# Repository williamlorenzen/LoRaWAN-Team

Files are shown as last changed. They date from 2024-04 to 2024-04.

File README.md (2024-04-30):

<!-- PROJECT LOGO -->
<br />
<p align="center">
  <a href="https://github.com/williamlorenzen/LoRaWAN-Team">
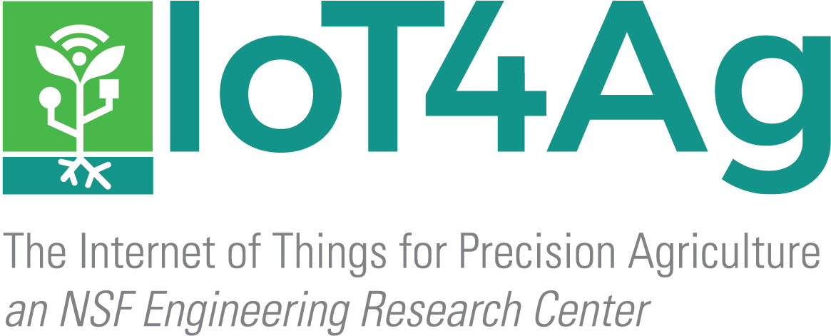
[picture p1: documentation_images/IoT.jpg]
    
  </a>

  <h2 align="center" style="font-size: 48px;">LoRaWAN Asset Tracker and Emergency Button</h2>

  <p align="center" style="font-size: 32px;">
    <strong>Spring 2024 LoRaWAN Team</strong>
    <br />
    William Lorenzen, Maria Barrera, Justin Nagovskiy
  </p>
</p>

<!-- TABLE OF CONTENTS -->
<details open="open">
  <summary>Table of Contents</summary>

## Table of Contents
- [Background](#background)
  - [LoRaWAN Overview](#lorawan-overview)
  - [Problem Overview](#problem-overview)
  - [LoRaWAN as a Solution](#lorawan-as-a-solution)
- [System Architecture](#system-architecture)
- [TheThingsNetwork](#thethingsnetwork)
  - [TTN Background](#ttn-background)
  - [TTN Applications](#ttn-applications)
  - [End Device Registration](#end-device-registration)
- [ThingSpeak](#thingspeak)
  - [ThingSpeak Account Creation](#thingspeak-account-creation)
  - [ThingSpeak Visualizations and Reacts](#thingspeak-visualizations-and-reacts)
  - [ThingSpeak Account Setup](#thingspeak-account-setup)
  - [Text Message Notification Setup](#text-message-notification-setup)
- [Gateway](#gateway)
  - [Option 1](#option-1)
  - [Option 2](#option-2)
- [Operation](#operation)
  - [End Node](#end-node)
  - [GPS Operation](#gps-operation)
  - [Bluetooth Uplink Communication](#bluetooth-uplink-communication)
  - [Downlink Communication](#downlink-communication)
  - [Farm Communication System and Future Work](#farm-communication-system-and-future-work)
  - [Python GUI](#python-gui)
- [Authors](#authors)
- [Acknowledgements](#acknowledgements)
</details>

<!-- Background -->
## Background

### LoRaWAN Overview

<p align="center">
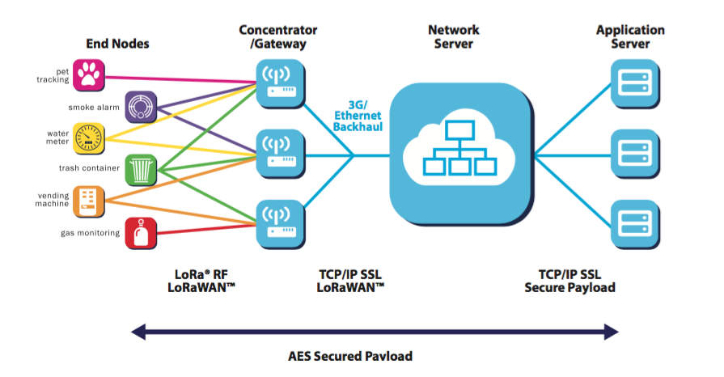
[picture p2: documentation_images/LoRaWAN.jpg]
	
</p>

LoRaWAN (Long Range Wide Area Network) is a networking protocol specially designed for low power, wide area applications. Introduced in the mid-2010s, LoRaWAN is known for its lower power consumption, cost-effectiveness, and longer range compared to traditional WiFi and cellular communications. However, it features lower bandwidth, which restricts its use for real-time, high data transfer applications. This makes LoRaWAN particularly well-suited for agricultural applications, where its long range and low power consumption are ideal for monitoring and reporting across extensive areas without requiring frequent battery recharges/replacements. To learn more about LoRaWAN, refer to [TheThingsNetwork's documentation](https://www.thethingsnetwork.org/docs/lorawan/).

### Problem Overview

The agricultural sector is recognized as one of the most hazardous industries in the United States, with a notable fatality rate of [23.5 per 100,000 workers](https://www.bls.gov/news.release/cfoi.nr0.htm). Two primary challenges complicate safety measures in this sector:

1. Asset Management: The extensive use of equipment and vast expanses of farmland make it difficult to monitor and manage assets effectively. Loss and misplacement of equipment are common issues, often highlighted during inventory checks.

2. Connectivity and Safety: Unreliable Wi-Fi and cellular connections in rural areas severely impact the implementation of safety measures. This connectivity gap poses a significant risk to worker safety, potentially leaving individuals isolated and unable to call for help during emergencies.

### LoRaWAN as a Solution

Given the limitations of conventional wireless communications like cellular and WiFi—namely their high cost and inadequate coverage in rural settings—LoRaWAN presents a viable alternative. Its low-cost, long-range capabilities allow for communication up to tens of kilometers in open conditions, addressing critical issues within the agricultural industry. 

To confront the safety and security concerns in the agricultural sector, our group developed a LoRaWAN-based end node that works as a personal emergency button as well as an asset tracker. Containing a GPS module, the end node collects its real time GPS coordinates and sends it in uplink messages to the server, along with other end node data, including the emergency status of the device, the battery voltage, and unique message codes that can be sent by field workers. Additionally, a Python application was created that will allow farm managers to view the real time GPS locations of the end nodes on a geolocation map, as well as the rest of the end node data. To ensure quick responses to emergencies, we have configured the server to send email and text notifications to relevant parties whenever the emergency button on the end node has been pressed. 

<!-- System Architecture -->
## System Architecture

<p align="center">
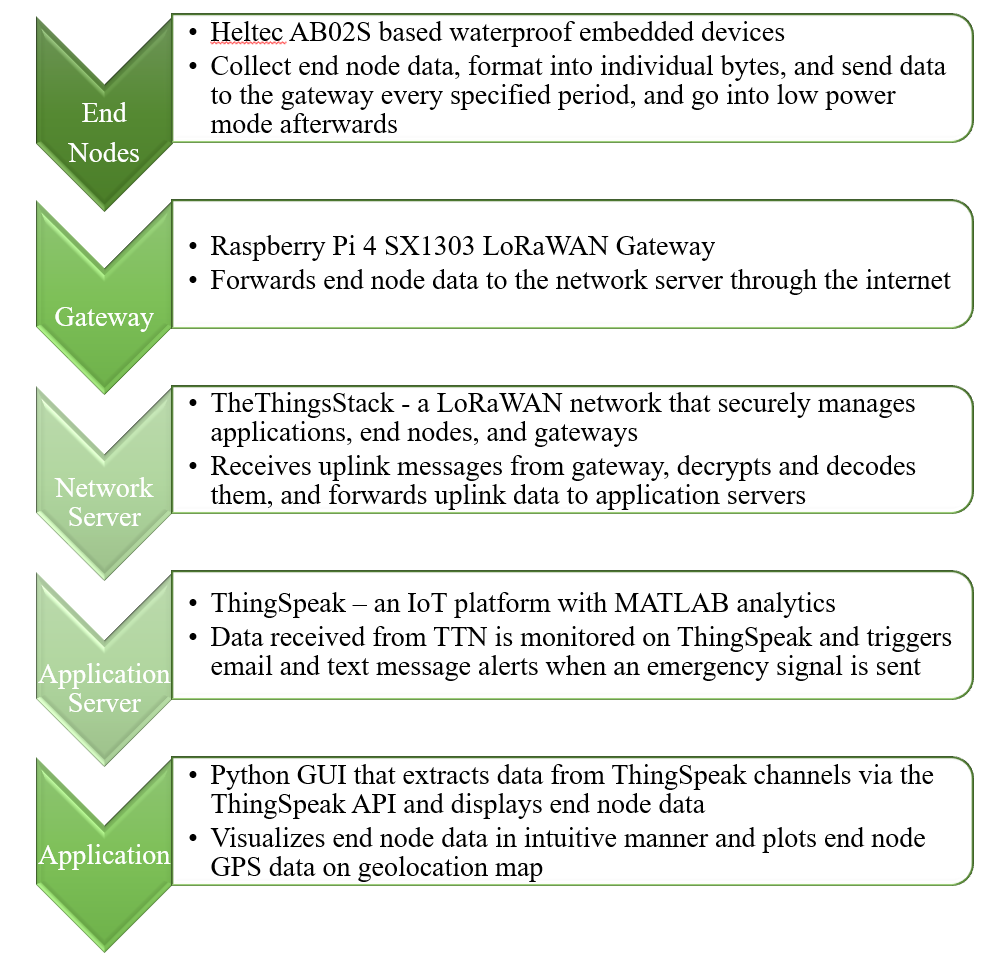
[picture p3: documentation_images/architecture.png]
	
</p>

Our system architecture is comprised of five primary components: the end nodes, the gateway, TheThingsNetwork, ThingSpeak, and a Python GUI. Please note that we refer to TheThingsStack, our network server, as TheThingsNetwork (TTN) in our documentation.

1. The end nodes are waterproof devices that are based around the [HTCC-AB02S](https://heltec.org/project/htcc-ab02s/), a development board that supports LoRaWAN communication and contains an Air530Z GPS and OLED display, making it optimal for our application. Please refer to the [hardware](hardware/) and [heltec_software](heltec_software/) folders, which each contain their own README files, for more information about the design of the end node.

2. The gateway is an SX1303 Raspberry Pi LoRaWAN gateway that was built and configured on TTN by the Fall 2023 LoRaWAN team. Additional information about the gateway and the instructions that the previous team used to set it up can be found [here](https://www.waveshare.com/wiki/SX1302_LoRaWAN_Gateway_HAT). If you want to learn how to set up a new gateway and configure it on TTN, refer to the [TTN documentation](https://www.thethingsindustries.com/docs/gateways/models/). The gateway is discussed in greater detail in the [Gateway section](#gateway).

3. TTN is our network server, where all of the uplink messages that are forwarded by the gateway are received, decoded, and forwarded to ThingSpeak. TTN is discussed in greater detail in the [TheThingsNetwork section](#thethingsnetwork).

4. ThingSpeak is our application server, where the data received from TTN is displayed and processed, allowing alerts to be triggered when an emergency signal is sent by an end node. Originally, we intended for ThingSpeak to act as the platform on which farm managers could view end node data and GPS locations, but due to limitations that are described in our report, we decided to develop a Python GUI to serve this purpose instead. The [ThingSpeak API](https://thingspeak.readthedocs.io/en/latest/api.html) allowed us to extract our end node data from ThingSpeak and use it in our GUI. ThingSpeak is discussed in greater detail in the [ThingSpeak section](#thingspeak) and [thingspeak_code](thingspeak_code/) folder.

5. The Python GUI extracts data from ThingSpeak, generating a fully interactive map displaying various end node locations and paths, as well as presenting end node data such as emergency status, battery charge, messages, and time since the last uplink message was received, all within a single interface. Please refer to the [gui_software](gui_software/) folder, which contains its own README file, for more information about the Python GUI.

For more detailed information about each of the system's components, please see our [final report on the project](resources/LoRaWAN_Spring_2024_Final_Report.pdf).

<!-- Operation -->
## TheThingsNetwork

### TTN Background 

TTN is the backbone of our system, with it receiving the uplink messages from our end nodes, decrypting and decoding the data, and forwarding the properly formatted data to ThingSpeak. TTN can also schedule downlink messages to particular end nodes, which we have implemented functionality for on our devices. 

On TTN, the gateway and end nodes must be configured appropriately in order to facilitate LoRaWAN communication. The LoRaWAN and Sentinel teams are using a shared TTN account for their implementations, on which the SX1303 gateway has already been configured. Future team members can reach out to [William](#authors) for the login information. As the gateway has already been configured on this shared account, configuration of the gateway on TTN will not be explained. TTN can be accessed [here](https://nam1.cloud.thethings.network/console/applications).

### TTN Applications

The important part of TTN for building upon our project or implementing other LoRaWAN based applications is the "Applications" tab. It is here that end devices are configured, which in our case is the HTCC-AB02S. We have designed our system so that each end node is configured in in its own unique application. This is because our TTN applications are configured to send decoded data to ThingSpeak, which then appears on ThingSpeak channels. The problem with these ThingSpeak channels is that there is a maximum of eight data fields per channel, meaning that a single ThingSpeak channel would not be able to handle the end node data of even two of our end nodes. Additionally, a single TTN application cannot be configured to send data from different end devices to separate ThingSpeak channels to circumvent the channel field limit. 

Therefore, we decided that our system would implement a dedicated TTN application for each of its end nodes, with each dedicated application sending end node data to a dedicated ThingSpeak channel. This way, each device was able to send eight fields of data to ThingSpeak, which was sufficient for our project and will allow future teams the bandwidth to send additional data from our end nodes, such as agricultural sensor data.

Establishing connection between TTN and ThingSpeak includes creating a webhook to a ThingSpeak channel from a TTN application. This process is explained in this [video](https://www.youtube.com/watch?v=b9Ga4nwnsTM).

### End Device Registration

The next step is to register an end device in an application. To do so: 

1. Click "Register end device" inside the relevant application.

2. Fill in the below information for the AB02S:

<p align="center">
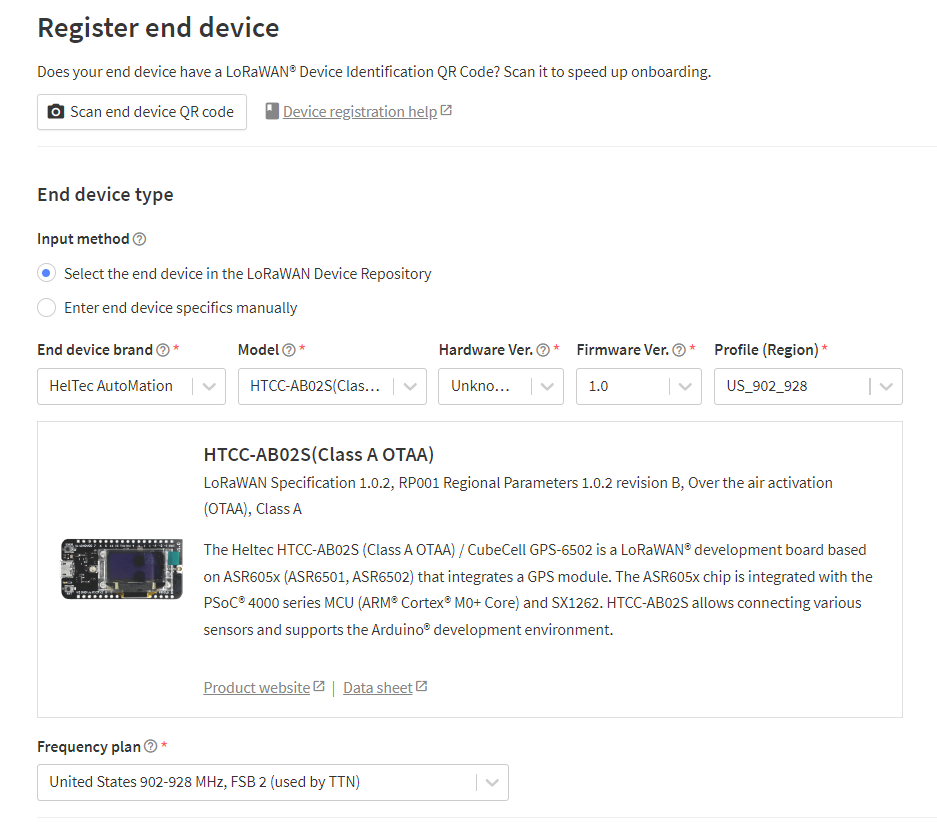
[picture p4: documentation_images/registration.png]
	
</p>

Depending on what brand or model that you use, the information may need to be different. But make sure you select your model with (Class A - OTAA), as is done in the image above. This is because end devices should be configured as Class A to reduce power draw, and OTAA communication should be used because it is more secure than ABP. More on [LoRaWAN classes](https://www.thethingsnetwork.org/docs/lorawan/classes/) and [communication types](https://www.thethingsnetwork.org/forum/t/what-is-the-difference-between-otaa-and-abp-devices/2723).

3. Input all 0's for the JoinEUI

4. Have TTN Generate the DevEUI and AppKey for you.

5. Go to your end node's script and update the DevEUI and AppKey to reflect the TTN generated information. For our project, this means going to the [GPS_LoRa script](heltec_software/GPS_LoRa/GPS_LoRa.ino) and updating the devEUI and appKEY arrays.

6. Click "Register end device." Your end device is now configured on TTN.

7. Click on the registered device and select "Payload Formatters."

8. For "Formatter type," select "Custom Javascript formatter."

9. Input your custom payload formatter, which decodes the payload that has been received from the end device. This should be tailored to the way in which you prepare your payload on your end node device. For our project, our TTN payload formatter was created according to how we filled the "appData" buffer in our GPS_LoRa.ino script. See the [heltec_software README](heltec_software/README.md) and [GPS_LoRA.ino script](heltec_software/GPS_LoRa/GPS_LoRa.ino) for more information. Our TTN payload formatter is below:

```
function Decoder(bytes) {
  // Decode an uplink message from a buffer
  var decoded = {};

  // Decode longitude
  var lng_frac_part = (bytes[0] | (bytes[1] << 8) | bytes[2] << 16);
  var lng_int_part = (bytes[3]);
  if (bytes[4] === 0xFF ){ //field 1
    decoded.lng = -1 * (lng_int_part + lng_frac_part / 1e6);
  } else {
    decoded.lng = (lng_int_part + lng_frac_part / 1e6);
  }
  
  // Decode latitude
  var lat_frac_part = (bytes[5] | (bytes[6] << 8) | bytes[7] << 16);
  var lat_int_part = (bytes[8]);
  if (bytes[9] === 0xFF ){ // field 2
    decoded.lat = -1 * (lat_int_part + lat_frac_part / 1e6);
  } else {
    decoded.lat = (lat_int_part + lat_frac_part / 1e6);
  }
  // button state
  if (bytes[10] === 0x00){
    decoded.button = 0; //not pressed
  } else if (bytes[10] == 0xFF){
    decoded.button = 1; //pressed
  }
  
  var bat_vol = (bytes[11] | bytes[12] << 8);
  decoded.bat = (bat_vol / 1e3);
  
  var message_code = bytes[13];
  decoded.message = message_code;

  //return decoded;
  return {
  field1: decoded.lng,
  field2: decoded.lat,
  field3: decoded.button,
  field4: decoded.bat,
  field5: decoded.message
  };
}
```

The combination of a ThingSpeak webhook and the returning of fields in the payload formatter ensures that data is sent to the ThingSpeak channel that is specified in the TTN "Integrations" tab. In our payload formatter, the longitude of the end node is sent to a ThingSpeak channel's field 1, the latitude is sent to field 2, the emergency status is sent to field 3, the battery voltage (V) is sent to field 4, and the message code is sent to field 5. These fields then show up on the ThingSpeak channel, as seen in the figures below.

<p align="center">
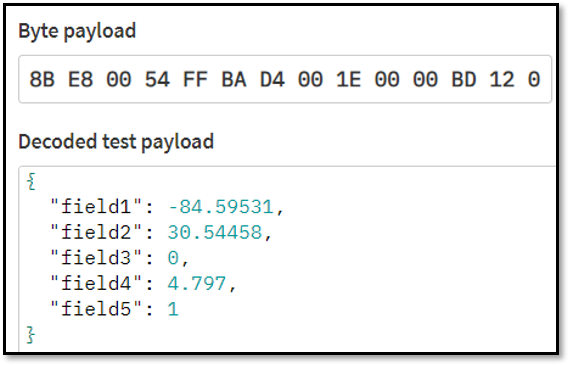
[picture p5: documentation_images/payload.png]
	
</p>

<p align="center">
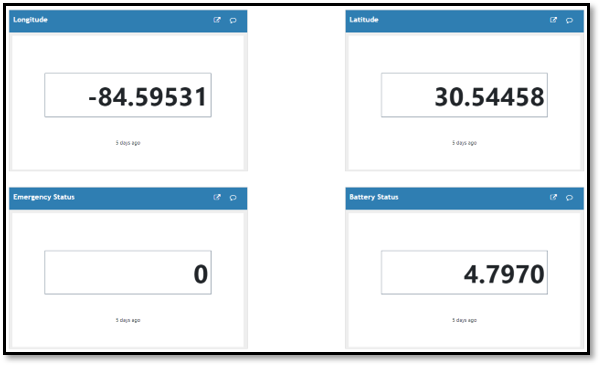
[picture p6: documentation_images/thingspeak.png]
	
</p>

With that, an end node can be been configured on TTN. When a new end node is being added to the system, a new application will have to be created, the end device registered, the relevant Javascript formatter code pasted into the payload formatter, a new ThingSpeak channel created, and the webhook to the new channel established.

<!-- ThingSpeak -->
## ThingSpeak

### ThingSpeak Account Creation

ThingSpeak is our application server where the data from TTN is sent and displayed, the emergency status flag is monitored, and an alert is sent to the email associated with the ThingSpeak account if the emergency flag is set to "1". There is no shared ThingSpeak account for LoRaWAN or Sentinel teams, so future teams will need to create a new MathWorks account (as ThingSpeak is a MathWorks service) for their project. The new MathWorks account should be created with a gmail account, not a UF email account. 

This is because you must configure forwarding rules on the email associated with the MathWorks account so that when a ThingSpeak alert is received, the email is forwarded to any relevant phone numbers. We found that UF emails do not allow for automatic forwarding of emails to members outside of the organization, so gmail must be used so that the alerts can be properly sent via text. If you want to access to the [Spring 2024 ThingSpeak account](https://thingspeak.com/login) to see our implementation, please reach out to [William](#authors).

### ThingSpeak Visualizations and Reacts

ThingSpeak is an IoT analytics platform that allows for analysis, visualization, and reacts through MATLAB. There is great documentation for it, which can be found [here](https://thingspeak.com/pages/how_to). Originally, we planned for ThingSpeak to be used by agricultural managers to view end node data and current locations, but due to every device needing to be on a different ThingSpeak channel and MATLAB visualizations being very small and non-interactive, we decided that a [Python GUI](gui_software) would serve this purpose instead. The limitations of ThingSpeak visualizations for our project can be seen in the small, low resolution output below. More on this visualization's source code is [here](thingspeak_code/).

<p align="center">
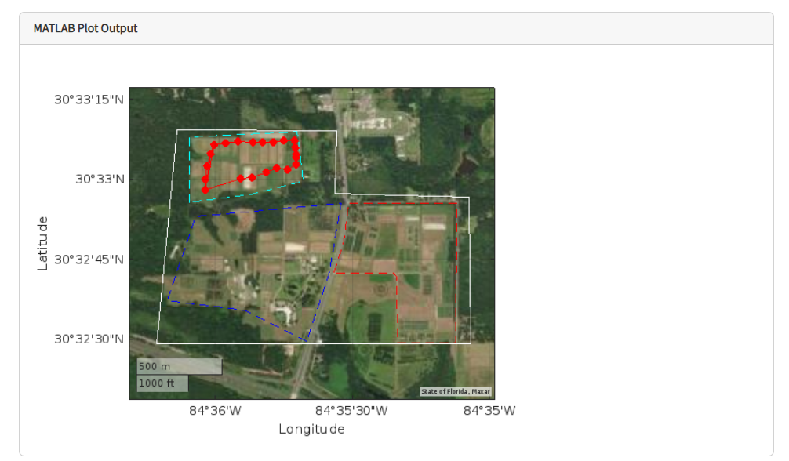
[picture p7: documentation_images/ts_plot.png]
	
</p>

Therefore, ThingSpeak is primarily being used in our project to host Reacts, which trigger preconfigured actions whenever a ThingSpeak channel meets a certain condition. We have configured Reacts for each channel associated with our systems devices such that the first time that field 3, associated with the emergency flag, switches from 0 to 1, an email is sent to the gmail associated with the ThingSpeak account, with the email containing the current GPS coordinates of the end node that sent the emergency signal. To better understand Reacts, refer to the [MathWorks documentation](https://www.mathworks.com/help/thingspeak/act-on-your-data.html). For reference, below is the react that was created for William's device:

<p align="center">
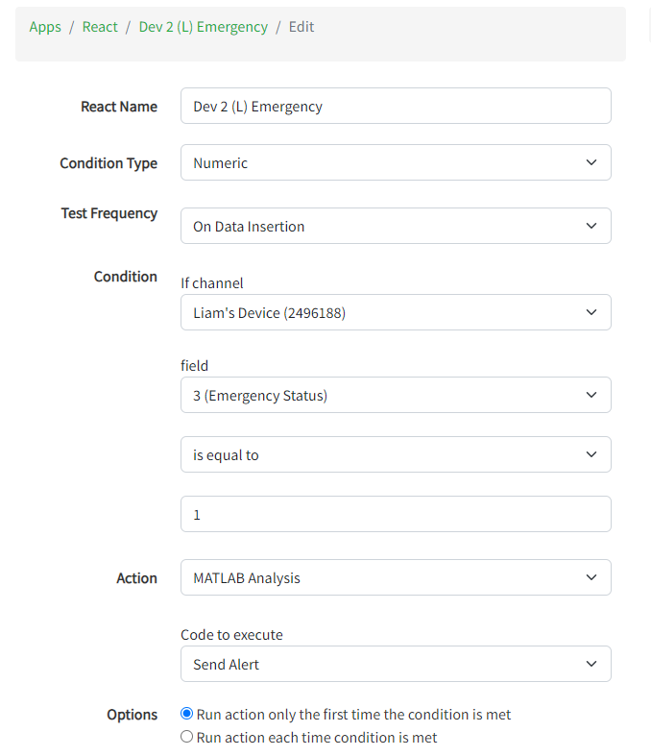
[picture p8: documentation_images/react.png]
	
</p>

This react ensures that when field 3 of channel 2496188 becomes "1", the ["Send Alert"](thingspeak_code/Send_Alert.txt) code is run. The Send Alert code then reads the fields associated with each emergency flag on the devices, and if a particular flag is equal to 1, a corresponding email alert is sent. It should be noted that the free version of ThingSpeak limits users to two ThingSpeak email alerts every 30 minutes. There is more on the Send Alert code and the "Boundary Flag" in the [ThingSpeak folder README](thingspeak_code/).

### ThingSpeak Account Setup

To fully set up your ThingSpeak account so that it fits with our system architecture, all that needs to be done is:

1. Create a new [ThingSpeak channel](https://thingspeak.com/channels) for each end node device. 

2. Under "Sharing," click "Share channel view with everyone." This makes the channel Public and will allow the Python GUI to extract data from the channel using the ThingSpeak API.

3. In TTN, alter each application webhook according to the new ThingSpeak channel IDs and Write API Keys associated with each end node.

4. Manually create Reacts for each ThingSpeak channel, with each of them triggering the "Send Alert" code.

5. Create a new MATLAB Analysis called "Send Alert" and paste [our code](thingspeak_code/Send_Alert.txt) into it.

6. Edit the channel IDs and Read API Keys in the Send Alert code to match with the new channels.

With that, your ThingSpeak account is fully set up and can easily be edited to accomodate more end nodes. Your TTN application webhooks and TTN payload formatters do the work behind the scenes to send data to the correct ThingSpeak channels, which you can view by doing "Add Visualization" for every field on your ThingSpeak channels, making the channel look like [this](https://thingspeak.com/channels/2496188).

It should be noted that the free version of ThingSpeak is limited to four channels. You can register for other [licenses](https://thingspeak.com/prices) to increase the number of channels. Or each team member could utilize a free membership, set up their accounts following the previously described steps, and have their TTN applications send to channels associated with the different accounts.
 
### Text Message Notification Setup

With your ThingSpeak account set up, ThingSpeak will send you an email like the one below whenever an emergency signal is received.

<p align="center">
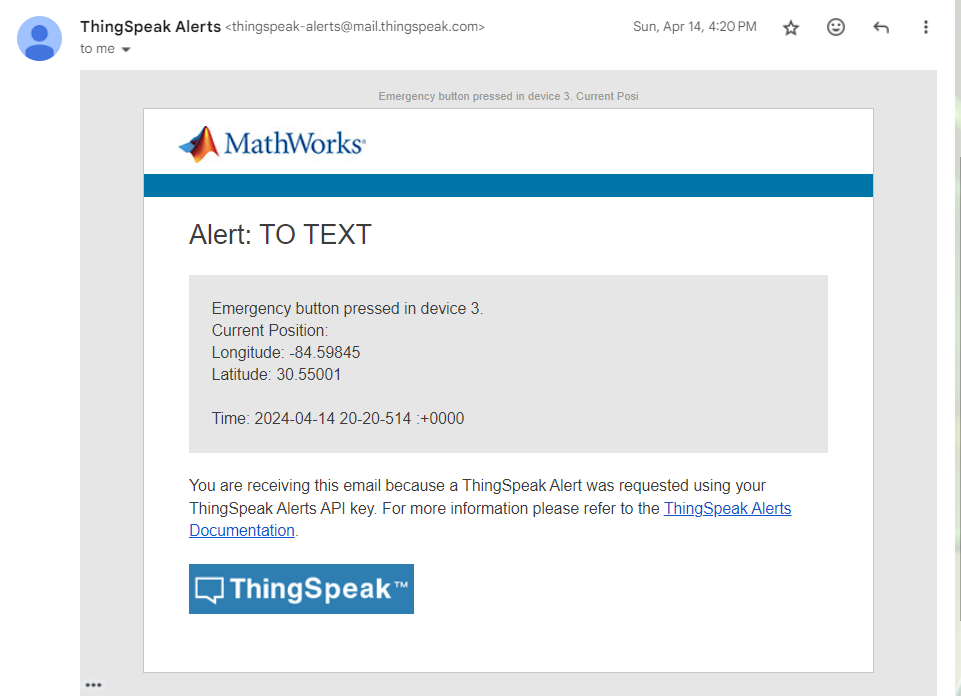
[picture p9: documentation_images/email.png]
	
</p>

We want this email to be automatically fowarded to relevant phone numbers via text, which will better facilitate an emergency repsonse. To do so, follow the steps in [this tutorial](https://www.instructables.com/Get-Gmail-To-Text-Emails-To-Your-Phone/), with some slight changes: 

1. Make sure that "Forwarding" in the "Forwarding and POP/IMP" tab is set to "Disable forwarding."

2. In the "Filters and Blocked Addresses" tab, click "Create a new filter."

3. In the "From" input cell, type "thingspeak-alerts@mail.thingspeak.com"

4. Click "Create Filter"

5. Check the box next to "Forward it to:" and select the relevant cellphone email address that you set up by following the linked tutorial. 

6. Verify the phone number.

7. Follow steps 2-7 for each phone that you want the alert forwarded to.

Please note that if Verizon is your carrier, use [10-digit phone number]@vzwpix.com rather than [10-digit phone number]@vtext.com, as the @vtext.com email has a message capacity that cuts forwarded emails short.

With that, your ThingSpeak account and text message alerts will be fully set up and you can receive alerts like the one below:

<p align="center">
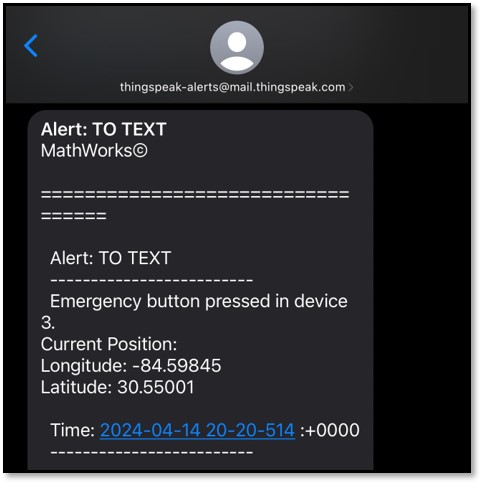
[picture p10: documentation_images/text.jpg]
	
</p>

<!-- Gateway -->
## Gateway

<p align="center">
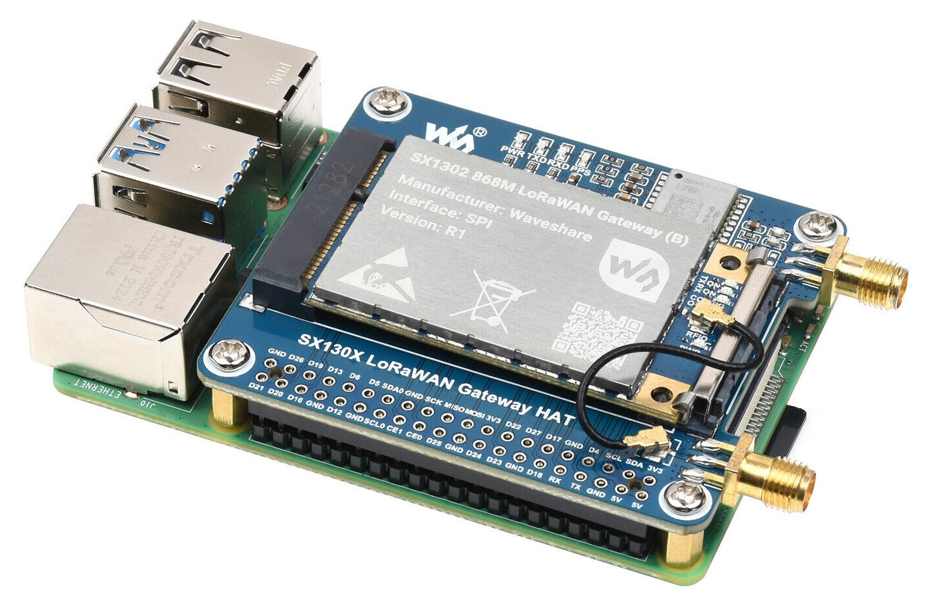
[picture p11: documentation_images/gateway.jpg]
	
</p>

The SX1303 Raspberry Pi gateway has already been fully setup and initialized on TTN. To connect the end nodes to TTN, the gateway needs to be connected to the server as well, which is done by powering up the gateway and running its packet forwarder. 

There are two options for connecting the gateway to the server:
1. SSHing in
2. Starting the packet forwarder directly on the Raspberry Pi

### Option 1:
1. Connect the gateway and your computer to the same WiFi network. You cannot use eduroam on the gateway, so you will either need to use your hotspot, or connect to the wifi that Dr.Eisenstadt has setup in NEB212. If you are using your hotspot, the gateway will not automatically join the first time, so you will need to directly startup the Raspberry Pi and connect to your WiFi hotspot manually, like in Option 2, so that the gateway knows your hotspot. Upon future bootups, the gateway will automatically connect to your hotspot.
2. Once the gateway and your computer are on the same Wifi, open up "command prompt" on your computer.
3. Paste:
	```
	ssh lora23@raspberrypi
	```
4. When prompted for the password, enter:
	```
	IoT4Ag
	```
5. When you have connected to the gateway, paste the following lines separately:
	```
	cd ~
	```
	```
	cd ~/sx1302_hal/
	```
	```
	cd packet_forwarder
	```
	```
	sudo ./lora_pkt_fwd -c test_conf
	```

### Option 2:
1. Connect an HDMI connector to the gateway and a monitor. Connect a mouse and keybord to the gateway.
2. Manually connect to your hotspot or other WiFi (not eduroam) on the Raspberry Pi.
3. Open up command prompt on the Raspberry Pi.
4. When you have connected to the WiFi, paste the following lines separately:
	```
	cd ~
	```
	```
	cd ~/sx1302_hal/
	```
	```
	cd packet_forwarder
	```
	```
	sudo ./lora_pkt_fwd -c test_conf
	```

The packet forwarder will now be running. You should see an error relating to the GPS on the gateway being constantly output to the command prompt. This is expected. When you look at the "Gateways" tab on TTN while signed into the shared account, you should see that the "waveshare-sx1303-eedesign2" gateway has its status listed as "Connected." 

The gateway needs to be connected to WiFi at all times to communicate with the server and receive information from the end nodes.

<!-- Operation -->
## Operation

This project has two primary end users: 

1. Agricultural workers who interact with the [end nodes](hardware/)
2. Agricultural managers who interact with the [Python GUI](gui_software/)

Each of these components have numerous use cases and were designed to be user friendly.

### End Node

The end node can be powered on by pressing the power switch - a round rocker switch embedded in the device's waterproof enclosure. The green status LED will turn on to indicate that the device is powered. The end user can then interact with the device by using the three buttons that are also embedded in the side of the enclosure. These buttons are:

- Emergency Button (red) - used to send emergency signal to server, which triggers email and text notifications so that help can be called

- Select Button (blue) - used to turn the Bluetooth communication module on/off

- Toggle Button (green) - used to toggle the OLED display on/off

<p align="center">
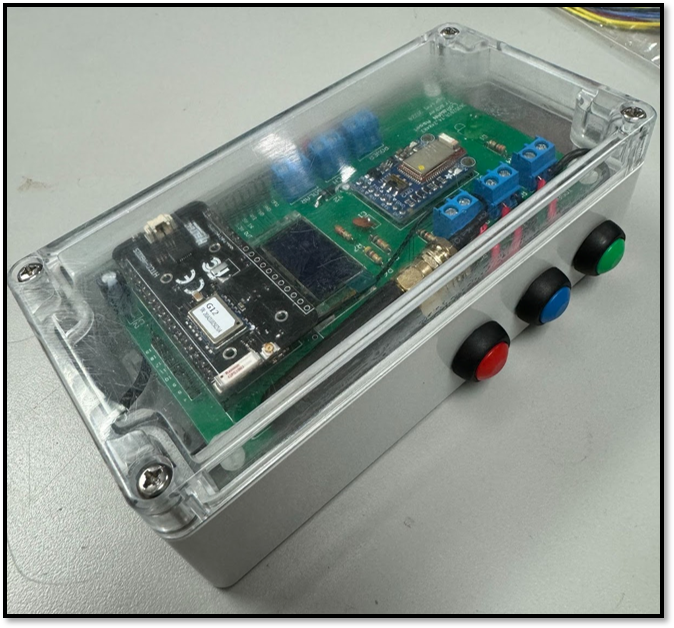
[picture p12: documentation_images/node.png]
	
</p>

The **Toggle Button** can be pressed once to make the current longitude, latitude, and battery voltage (mV) of the end node appear on the OLED display. When the toggle button is pressed again, the OLED display will be cleared and turned off.

The **Select Button** can be pressed once to turn Bluetooth communication on, which results in a corresponding message being displayed on the OLED. When the Select button is pressed again, Bluetooth communication is turned off and, again, a corresponding message is displayed on the OLED. Bluetooth communication with the end node is discussed more in the [Bluetooth Communication](#bluetooth-uplink-communication) section of this README.

The **Emergency Button** can be held down once to trigger a message on the OLED display asking the user if they want to send an emergency signal. If they do, they can hold down the emergency button once again, and the emergency signal will be sent in the next uplink message to the server. A message then appears on the OLED stating that the emergency signal has been sent. 

If the emergency button was accidentally held down once and it is not held down again within a 10 second window, then the OLED message will be cleared, and the emergency button will once again have to be held down twice to send an emergency signal. This protects against an emergency signal accidentally being sent, which triggers email and text notifications and could cause first responders to be called unnecessarily.

A video of the end node button's functionalities can be found [here](https://www.youtube.com/watch?v=o7ewifo6IbQ&t=4s). A video of the emergency button functionality and its interaction with TTN, ThingSpeak, and the Python GUI can be found [here](https://www.youtube.com/watch?v=NjQwIZdp0Hk&t=1s).

### GPS Operation

The device is programmed to start the GPS upon bootup, but it can take some time for the GPS to fix onto the four satellites required for the longitude and latitude to be determined. When the GPS has fixed, a green LED on the HTCC-AB02S starts to flash and the OLED displays the time that it took for the GPS to fix. The GPS remains fixed whilst the Heltec is in low power mode between uplink messages, meaning that the GPS has to only fix once upon bootup and after every time that Bluetooth communication is initiated and stopped (which is not expected to be frequent). 

A video of the end node's GPS fixing and real time GPS data being sent to TTN, ThingSpeak, and the Python GUI can be found [here](https://www.youtube.com/watch?v=rXeL1cVMSls&t=5s). Emergency button functionality was once again demonstrated in this video. 

### Bluetooth Uplink Communication

The end node contains an [Adafruit Bluetooth Low Energy module](https://www.adafruit.com/product/2633#description), which will allow field workers to transmit unique messages to the server using their phones. The BLE module was chosen both because of its Arduino support and because it has a dedicated iOS app that will allow users to easily interface with it. To establish Bluetooth connection and send messages to the server, the end user need only:

1. Open up their iPhone and download the [BluefruitConnect](https://play.google.com/store/apps/details?id=com.adafruit.bluefruit.le.connect&hl=en_US&gl=US) app from the App Store.

2. Press the Select (blue for BLE) Button on the end node. The OLED will display: "Turning on BluetoothLE".

2. Open up the app and make sure that the "Must have UART Service" setting is turned on to filter out extraneous Bluetooth connections. 

3. Connect to the relevant Bluetooth connection, which has its name configured by the NEW_BLE_NAME macro in our [Heltec code](heltec_software/GPS_LoRa/GPS_LoRa.ino). When their phone has connected to the BLE, a blue LED will light up on the BLE module.

4. Select UART, which will open up a chat interface.

5. Type into the text input field one of the 7 code words corresponding to a particular uplink message that will be sent to the server. These code words are preconfigured in the GPS_LoRa.ion script and can be easily changed or added to by future teams: 

| Code Received | Corresponding Message  |
|---|---|
| `complete` | Task complete |
| `start` | Starting Task |
| `hand` | Need a hand |
| `repair` | Repair Needed |
| `pest` | Pest Sighting |
| `malf` | Equipment Malfunction  |
| `deliv` | Deliveries Arrived |

6. View the corresponding message being displayed on the end node's OLED. For example, if "hand" is sent by the end user, the OLED will display "Going to send: Need a hand". The message can be changed to a different one before the message code is sent to the server.

7. Either submit the message "send" to the app's chat interface or press the Select (BLE) button on the end node again. This will turn off BLE communication, reinitialize LoRaWAN connection with the server, and send the message to the server in the next uplink, where it can be viewed on the Python GUI. 

8. To send another message, the end user will need to turn the BLE module back on and reconnect through the app again.

A video of the Bluetooth connection, interfacing, and the resulting messages on the Python GUI can be found [here](https://www.youtube.com/watch?v=-xSc22rfDIg&t=1s).

An added feature of the BLE module is that although the end user must turn BLE communication on and off in order to interface with the device, the module is always connected to the end node's power supply, meaning that the BLE constantly beacons while the end node is turned on. This can allow agricultural workers to detect when they are near particular assets by monitoring the names of the Bluetooth beacons that appear in the BluefruitConnect App, which can make it easier for them to check that asset off as being in inventory. 

<p align="center">
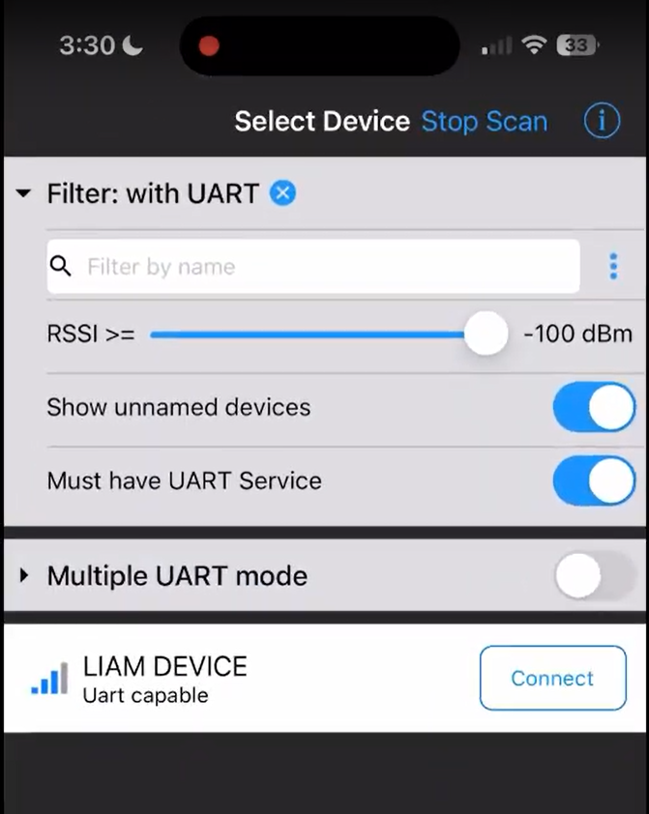
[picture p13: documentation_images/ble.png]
	
</p>

For example, an end node programmed to be mounted on "Tractor 321" could have the name of its Bluetooth beacon changed to "Tractor 321" using the NEW_BLE_NAME macro in our GPS_LoRa code. Then, when farm workers are doing inventory, they can walk around the general area where the end node attached to "Tractor 321" was seen on the the Python GUI, open the BluefruitConnect app and view the "Tractor 321" bluetooth beacon, and mark "Tractor 321" as being in inventory.

### Downlink Communication

The end nodes also feature downlink communication, meaning that messages can be sent from the server down to individual end nodes. We have configured specific downlink codes to trigger particular messages being displayed on an end node's OLED for 10 seconds, after which the OLED is cleared. These messages can be read by nearby agricultural workers and can facilitate long range communication between field workers and managers in rural regions that do not have cellular connection. The table of preconfigured downlink codes and their corresponding OLED messages are below:

| Downlink Data (Hex) | Downlink Data (Decimal) | Corresponding OLED Message  |
|---|---|---|
| `0x1231` | `4657` | Return within Bounds |
| `0x1232` | `4658` | Return to Base |
| `0x1233` | `4659` | Move to Field A |
| `0x1234` | `4660` | Move to Field B |
| `0x1235` | `4661` | Rain Expected |
| `0x1236` | `4662` | High Heat Alert |
| `0x1237` | `4663` | Return Device to Base |

To send a downlink message, the agricultural manager need only:

1. Open up [TTN](https://nam1.cloud.thethings.network/console/applications) and log in with our shared credentials.

2. Open up the application that corresponds to the end node that they want to communicate with. 

3. Open up the application's end device.

4. Go to the "Messaging" tab and then the "Downlink" section.

5. Type in a Hex code from the above table into the "Payload" input field, ensuring that it matches with the corresponding message that they want displayed on the end node's OLED.

6. Check the box next to "Confirmed downlink"

7. Click "Schedule Downlink" 

We are using Class A devices, meaning that after every uplink message, there are two short windows in which downlink messages can be received by the end node. So, after the downlink is scheduled and after the next uplink message is sent by the respective end node, the message corresponding to received hex code will be displayed on the end node's OLED for 10 seconds.

A video of the downlink message process and the corresponding OLED displays can be found [here](https://www.youtube.com/watch?v=OvLeOCoEfU0).

### Farm Communication System and Future Work

The Bluetooth uplink messages and TTN downlink messages can facilitate communication between field workers and managers via LoRaWAN in locations that do not have cellular connection. For example, a field worker could use their phone to send the code "water" to the end node, which would show up in the Python GUI as "In urgent need of water" in the corresponding device's message box. The manager could see this, identify the current GPS coordinates of that end node, and have another worker drive to the end node's location to provide the worker with water. The manager could send a downlink message corresponding to "We are on our way" to the respective end node so that the worker would know that help is coming. 

Additionally, either Bluetooth codes or downlink codes could be used to control many other future features of the end node, whether that be actuating motors or turning on additional sensors for environmental monitoring or equipment diagnostics, providing a scalable and versatile tool for agricultural management. A vibration motor could be added to the end node, which could be triggered when a downlink message is received, notifying nearby workers to look at the OLED display to see what the manager sent. 

The BLE module's VCC pin could be connected to a FET that is connected to the end node's battery and that is controlled by a GPIO pin, allowing the BLE module to be turned on and off through software. This would not only make the end node more power efficient by not having the BLE module powered at all times, but the end node could be configured so that if a particular downlink code was received, the BLE would remain on until a different downlink message code was received that told it to power off. 

This could allow a farm manager to tell particular end nodes to beacon Bluetooth signals with the names of the assets that they are attached to, which would allow a farm worker to walk around with the BluefruitConnect open on inventory day, view all the nearby beacons, and mark these assets as being in inventory, which could quicken the lengthy and tedious inventory process. Perhaps then the farm worker could connect to the BLEs of the nearby beaconing devices, send a code word corresponding to inventory ("inven"), and the corresponding device's message box would appear as being "In Inventory" in the Python GUI, which could be seen by the agricultural manager.

These are just ideas, but there are many ways in which this project can be built upon to address different agricultural challenges.

### Python GUI



The Python GUI is intended to be used by agricultural managers so that they can monitor the current locations of the end nodes, the paths that the end nodes traveled on particular days, and the rest of the end node data, including battery charge, messages, time since the last uplink was received, and emergency status. The GUI offers additional features, such as displaying polygons representing different fields on an agricultural site (allowing users to easily identify which end nodes are in which fields), automatic snapping to and plotting on the map the locations of end nodes that sent emergency signals, a feature to toggle the polygons on and off, and a feature to snap the map to the last received location of particular end nodes. 

This is best demonstrated with a [video](https://www.youtube.com/watch?v=8F29PMxJtjw).

After the GUI is opened, its fields must be manually updated by clicking "Get Latest" buttons. When this is done, there is no discernible latency between the uplink message being received by TTN, the decoded data being sent to ThingSpeak, and the data being plotted and displayed on the Python GUI. This is best demonstrated in a [video](https://www.youtube.com/watch?v=JTSg13Apyt0). 

In this video, we sent mock GPS data from an end node, making it look like it was traveling across the Quincy, FL site, which can clearly be seen in the Python GUI. Note that the GUI was somewhat laggy in the video because I had to have my computer connected to my phone's hotspot whilst being SSHed into the gateway.

<!-- Authors -->
## Authors

| Name | Email | Phone |
|---|---|---|
| William Lorenzen | [liamv1200@gmail.com](mailto:liamv1200@gmail.com) | 813-777-3454|
| Maria Barrera | [maria.barrera@ufl.edu](mailto:maria.barrera@ufl.edu) | 786-319-6846|
| Justin Nagovskiy | [jnagovskiy@ufl.edu](mailto:jnagovskiy@ufl.edu) | 954-258-6993|

Please contact William Lorenzen for any inquiries or issues related to the project.

Project Repository on GitHub: https://github.com/williamlorenzen/LoRaWAN-Team

<!-- Acknowledgements -->
## Acknowledgements

We would like to thank our senior design faculty sponsor, Dr. Eisenstadt, for his guidance on this IoT4Ag project. We would also like to thank Professor Mike Stapleton for his help with hardware design, Dr. Ian Small for his user interface suggestions, and Eric Liebner for his help with the enclosure and parts.

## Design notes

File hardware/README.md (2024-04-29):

# Hardware

## System Overview

The hardware is composed of two primary subsystems: the Heltec [AB02S development board](https://heltec.org/project/htcc-ab02s/) and the [Adafruit Bluetooth Low Energy UART module](https://learn.adafruit.com/introducing-the-adafruit-bluefruit-le-uart-friend/introduction). The Heltec controls much of the system's functionality, containing the ASR650x MCU (a combination of the PSoC4000 microcontroller and the SX1262 LoRa transceiver) that dictates the end node's operation. Both modules operate on an Arduino framework, allowing for easier integration. We designed a PCB that joins these boards together and integrates the system's other peripherals, including its three buttons, status LED, female header expansion pins, and power switch. The end node is powered by a 5V Miady battery and is enclosed in a waterproof polycarbonate box.

- Power Switch - turns the end node on
- Three Buttons:
	- Emergency Button (red) - used to send emergency signal to server, which triggers email and text 	notifications so that help can be called
	- Select Button (blue) - used to turn the BLE module on/off
	- Toggle Button (green) - used to toggle the OLED display on/off
- Status LED - lights up when end node is on
- Expansion Female Headers - can be used to add external sensors or modules to the end node

## Altium Project

The PCB was designed in Altium and is in the "LoRaWAN Senior Project" folder in this repository. Additionally, a bill of materials was created. The schematic and PCB can be seen below.

<p align="center">
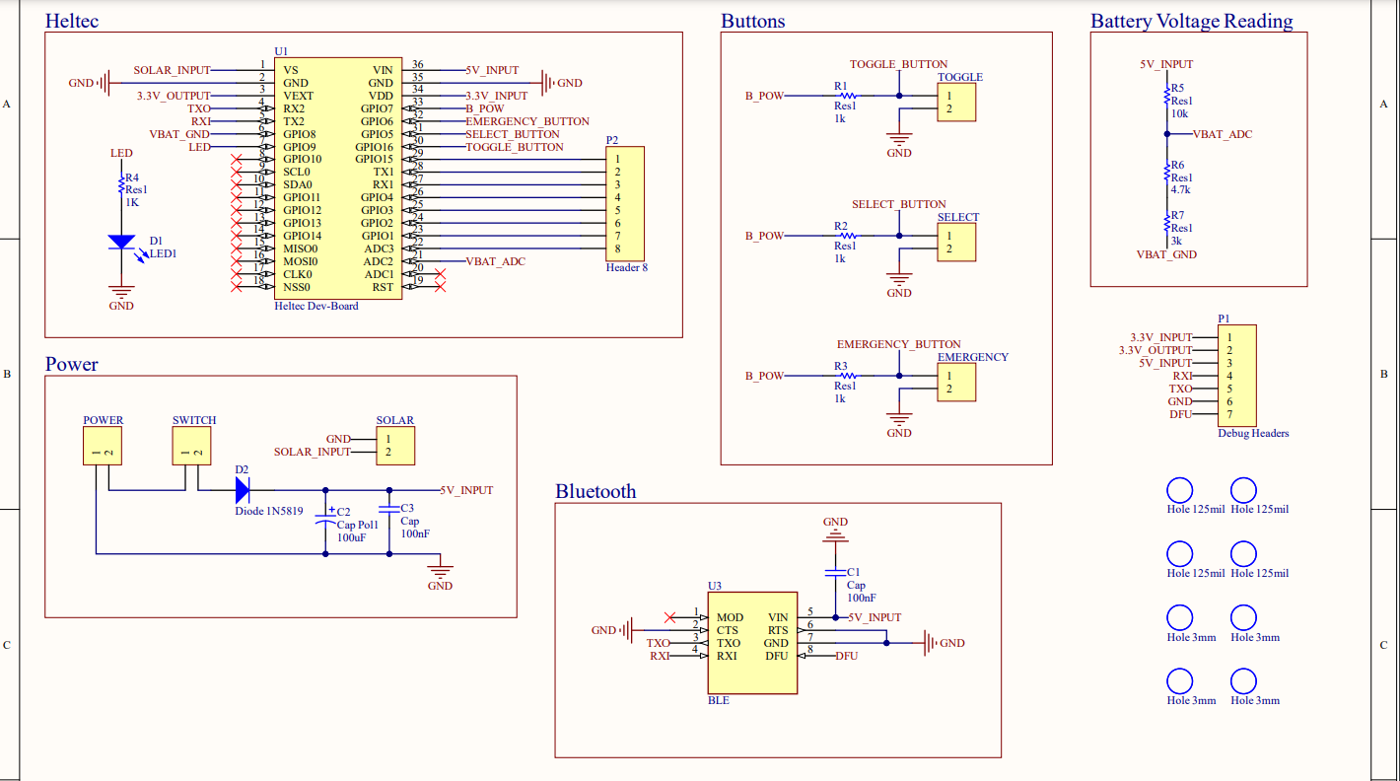
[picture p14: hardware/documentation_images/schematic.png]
	
</p>

<p align="center">
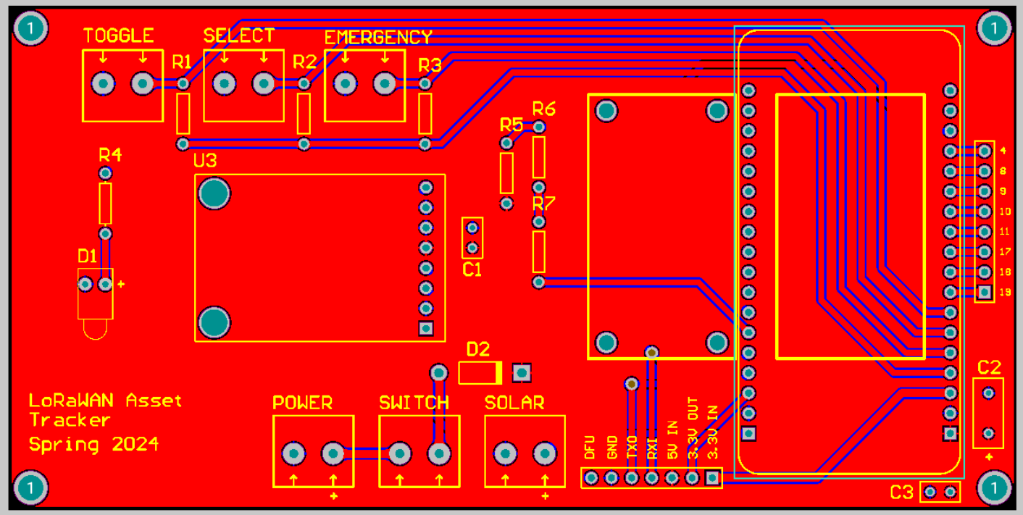
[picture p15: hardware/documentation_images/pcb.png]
	
</p>

A strange design choice by Heltec when designing the AB02S was to place the GPS antenna on the underside of the board, opposite the OLED display. As the AB02S's Air530Z GPS already takes quite a long time to fix, sometimes taking up to several minutes outside, we knew that having the GPS antenna pointed down into our PCB would only worsen this problem. As the OLED display is wired to the AB02S using a flexible printed circuit, we decided to unscrew the OLED from the AB02S, flip it so that it hung from the side of the development board and was pointing in the same direction as the GPS antenna, and mount the OLED to our PCB with the AB02S alongside it. This way, both the GPS antenna and OLED display were pointing towards the top of our end node.

<p align="center">
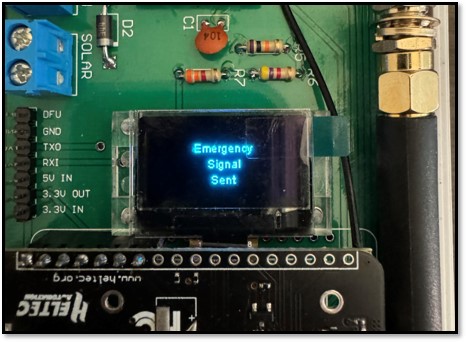
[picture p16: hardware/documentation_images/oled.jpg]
	
</p>

## End Node

Pictures of the end node can be seen below. The emergency (red), select/BLE (blue), and toggle (green) buttons are embedded in the waterproof box.

<p align="center">
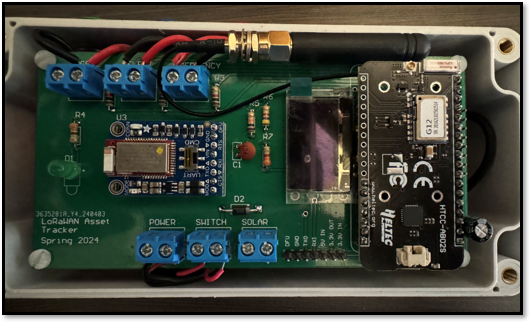
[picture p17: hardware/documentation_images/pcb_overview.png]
	
</p>

<p align="center">
	
</p>

Caulk still needs to be applied to seal the gaps between the buttons, power switch, and the enclosure to ensure waterproofing.

## Future Work

There are quite a few hardware items that future teams may consider working on to build upon this project, or at least that they can keep in mind when pursing their own:

### Miniaturization of End Node 
- our end node is very bulky, making it suitable to be mounted on large equipment like tractors, but not wearable
- there is definitely room to shrink our PCB, as SMDs can be used and there is lots of empty space on our PCB
- a concern is that the Bluetooth or LoRaWAN signals may be impeded if everything is crowded too close together

### Addition of Peripherals
- peripherals can be added to our end nodes by connecting them to the female header pins located on the edge of the board
- these peripherals can include environmental sensors, and the system can be updated to transmit the sensor readings to the server, where they can be viewed on the GUI once it is updated
- a vibration motor was discussed as a possibility in the main branch's README file

### Battery Updates
- transition from a 5V Miady battery to a 3.7V LiPo battery to power the end node will allow the end node to be more easily miniaturized, as the Miady battery is very bulky
- additionally, use of a LiPo may allow for more accurate mapping of the end node voltage to battery charge percentage

### Gateway Improvements
- a hardware improvement for the gateway is to possibly transition to using the Raspberry Pi 5 for the SX1303 Gateway to avoid the heat generated by the Raspberry Pi 4
- currently, the gateway gets incredibly hot after only a few minutes of operation, which caused us to never have it on for long periods of time and never consider having it permanently powered on in NEB212
- transition to a Raspberry Pi 5 or other LoRaWAN gateway that could always be powered on and would not have to be SSHed into whenever it was booted up would be incredibly nice for future teams

### Miscellaneous
- extensive testing in the field is required to ensure that the end node maintains charge for long periods of time
- alter the PCB so that the BLE's VCC is connected to a FET rather than the battery's 5V input, which will allow the BLE to be turned on and off by software, rather than constantly on. As mentioned in the main branch's README file, this would make the end node more power efficient
- the LoRaWAN signals would be far less prone to attenuation if the antenna could be mounted on the outide of the enclosure (and the antenna's wire is long enough to do this)

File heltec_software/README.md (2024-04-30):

# Heltec AB02S Code

## Dependencies

<p align="left">
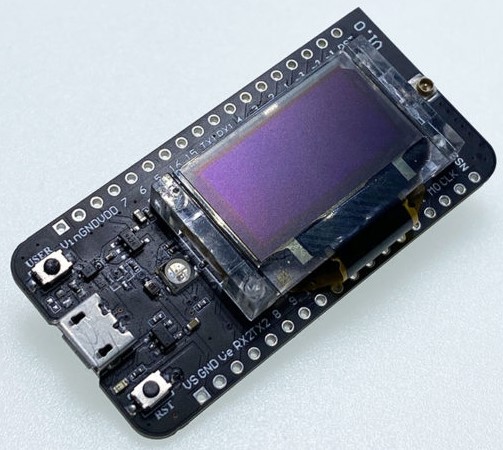
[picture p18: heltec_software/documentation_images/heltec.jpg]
	
</p>

Our end nodes are controlled by Heltec CubeCell (ASR-650X) Development Boards, specifically the [AB02S](https://resource.heltec.cn/download/CubeCell/HTCC-AB02S). Heltec has created Arduino Frameworks for their development boards that simplifies establishing LoRaWAN communication and programming additional functionalities. To program the boards:

1. Install the CubeCell framework through the [Arduino board manager](https://docs.heltec.org/en/node/asr650x/htcc_ab02s/quick_start.html).

2. Establish serial connection by installing the [USB driver](https://docs.heltec.org/general/establish_serial_connection.html).

3. Go to where the CubeCell folder was automatically downloaded in Step 1 and replace it with the CubeCell folder in this repository. For reference, my CubeCell folder was saved in this path: C:\Users\[user]\AppData\Local\Arduino15\packages\CubeCell. This step is necessary because I had to make a lot of miscellaneous changes in the framework's source files for our application.

4. Place the Adafruit_BluefruitLE_nRF51 folder in this repository into your Arduino libraries folder. For reference, my libraries folder was saved in this path: C:\Users\[user]\OneDrive\Documents\Arduino\libraries. 

5. Open the GPS_LoRa.ino file, located in the GPS_LoRa folder in this repository, locally.

6. Under "Select Board" in Arduino, select the "CubeCell-GPS（HTCC-AB02S)".

7. Ensure the correct LoRaWAN settings under "Tools," as shown below.



You are now ready to program various AB02S boards with our program and change it according to your project's goals.

## How it Works

Our code is modeled off of the [LoRaWAN.ino example script](CubeCell/hardware/CubeCell/1.5.0/libraries/LoRa/examples/LoRaWAN/LoRaWan/LoRaWan.ino) provided by Heltec, with added functionality. This example script's main loop is controlled by a switch case, where each switch block corresponds to a different step in the LoRaWAN communication protocol. The DEVICE_STATE_INIT block initializes the LoRaWAN parameters, the DEVICE_STATE_JOIN block facilitates server connection, DEVICE_STATE_SEND prepares the payload of a frame and sends an uplink message to the server, DEVICE_STATE_CYCLE schedules the next packet transmission, and DEVICE_STATE_SLEEP places the Heltec into low power mode.

Upon the Heltec booting up, LoRaWAN communication will be initialized in DEVICE_STATE_INIT and the program will enter DEVICE_STATE_JOIN to attempt to join the server. If the Heltec cannot establish communication with the server in a specified period of time, the board goes into low power mode in DEVICE_STATE_SLEEP for 30 seconds, after which it attempts to join the server once again. If the Heltec establishes a connection to the server, it joins DEVICE_STATE_SEND, where desired uplink data is formatted into individual bytes, loaded into a buffer, and transmitted to the server in an uplink message. After this, DEVICE_STATE_CYCLE is entered, in which a timer is initialized with a preconfigured period (the default is 15 seconds) and the program promptly switches to DEVICE_STATE_SLEEP. In this final switch block, the device remains in low power mode until the timer initialized in the previous step overflows, prompting the timer's Interrupt Service Routine that returns the program to DEVICE_STATE_SEND so that another frame can be sent to the server after the sleep period. The program continues in this loop of sending data to the server and sleeping for a specified amount of time indefinitely. Of course, this is a simplification of the program, but it encompasses the main functionality of the LoRaWAN.ino script.

To write our end node script, we added to this example script by configuring the device to receive button inputs and trigger corresponding ISRs, display messages on the OLED, facilitate communication with the Adafruit BLE module, and collect our end node data, including longitude, latitude, emergency status, battery voltage, and message codes. Some notable parts of the code that are important to understand are:

1. The OTAA parameters need to be changed according to configurations in TheThingsNetwork (TTN) and need to be unique for every device configured on TTN.

2. The “appTxDutyCycle” variable specifies the approximate time in ms between transmissions to the server (approximate because there is a random small addition to this number to stop two devices from sending information at the same time).

3. The “prepareTxFrame” function prepares data to be sent to the server. In this function, the "appDataSize" variable is specified with the number of bytes that are going to be sent and the payload is formatted by storing individual bytes of end node data into the "appData" buffer. This payload will be decoded by a payload formatter on TTN once the uplink message is received.

The GPS_LoRa.ino script has been extensively commented so that it may be added to or used as a model for future LoRaWAN team implementations. It should be noted that the last time that the board was programmed, it was done so with "debug = 1," making the end node send mock GPS data to the server for demonstration purposes. Set "debug = 0" for real GPS coordinates to be sent to the server.

## Important Note

Something to keep in mind is that the GPS_LoRa.ino code, as well as all relevant dependencies, take up 93% of the AB02S's program storage space (122235 bytes of the 131072 maximum). I am genuinely not sure how much this may present as a limitation for building upon our script, as the LoRaWAN.ino script alone takes up about 70% of storage space. With most of the AB02S's relevant peripherals already integrated into our script, the essential dependencies required for these components are also already loaded into the program’s storage space. This effectively reduces the additional storage needed for any new peripherals that rely on these existing dependencies, which may mean may there is still some room to add to our program, such as by adding sensors or other peripherals. This storage utilization is definitely a concern for further growth though, and may necessitate the use of other MCUs, such as the Photon, which Dr. Eisensatdt has in abundance.

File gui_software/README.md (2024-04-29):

# Python GUI Application



## Dependencies

1. To run the Python GUI code, you will need jupyter notebooks, which you can access by installing [Anaconda](https://docs.anaconda.com/free/anaconda/install/windows/) and [Anaconda Navigator](https://docs.anaconda.com/free/navigator/install/).

2. Once they are installed, open up Anaconda Navigator, click on "Environments" and create a new environment with the Python package installed (the default Python 3.10.14 version is fine).

3. Open up Anaconda prompt and run: 
	```
	conda activate [name of your environment]
	```

4. Download the required packages by running:
	```
	conda install -n test jupyter
	```

	```
	pip install customtkinter
	```

	```
	pip install tkintermapview
	```

	```
	pip install thingspeak
	```

	```
	conda install numpy
	```

5. Open up jupyter notebooks in your environment by running:

	```
	jupyter notebook
	```

6. Navigate to the "LoRaWAN_GUI.ipynb" file and open it. The code is ready to be run. To ensure that there are no errors, make sure that you select "Kernel->Restart and Run All Cells" everytime that you want to reopen the GUI.

## How It Works

The Python GUI extracts data from our ThingSpeak public channels, where each channel is dedicated to a single device. The data is extracted using the [ThingSpeak API](https://thingspeak.readthedocs.io/en/latest/api.html) and custom made functions and it is then displayed in the GUI, which was created using the [CustomTkinter](https://github.com/TomSchimansky/CustomTkinter) and [TkinterMapView](https://github.com/TomSchimansky/TkinterMapView) libraries, which have very good documentation and [tutorials](https://customtkinter.tomschimansky.com/tutorial/).

The GUI was created with scalability in mind, allowing future teams to easily add additional devices to it. Doing so requires only two changes to the code:

1. Updating the "Device_Lookup" dictionary to reflect the new quantity of devices to be displayed, along with their corresponding ThingSpeak channel IDs. Of course, this necessitates creating new TTN applications and ThingSpeak channels for each additional device and configuring them accordingly (payload formatters and webhooks).
2. Updating the "values" list to reflect the new device names within the "Device_Lookup" dictionary.

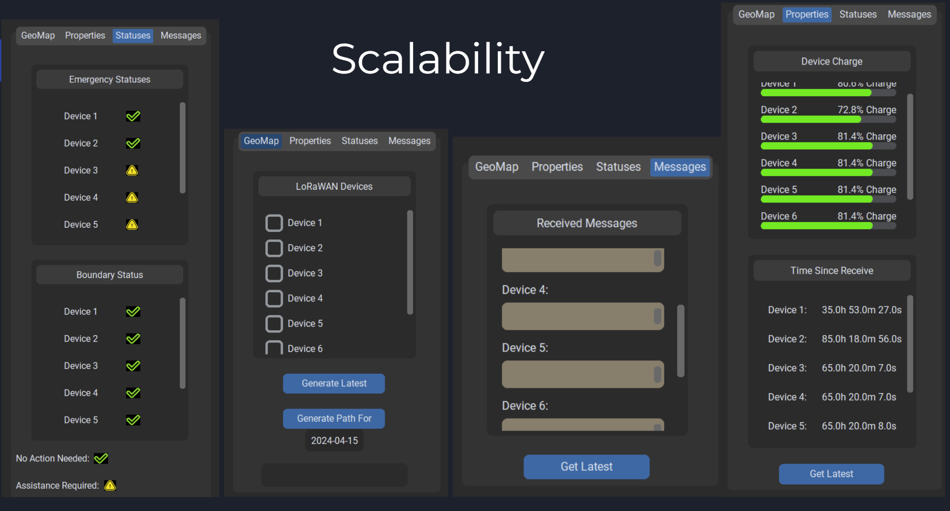
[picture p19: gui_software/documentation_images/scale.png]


The GUI code has been extensively commented so that it may be added to or used as a model for future LoRaWAN team implementations.

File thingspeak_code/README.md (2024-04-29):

# ThingSpeak Code

## Alert

The Send_Alert file contains the code that should be pasted into a new MATLAB Analysis in ThingSpeak. After the directions are followed in the ThingSpeak section of the main branch's README, this code will be run whenever any React on the ThingSpeak account is triggered.

This code then reads the fields associated with each emergency flag on the devices, and if a particular flag is equal to 1, a corresponding email alert is sent. If the emergency flag of an end node is detected as being "1," that end node's current GPS location is extracted and included in the email alert.

## Visualization

The ThingSpeak_Plotting file contains code that can be pasted into a MATLAB Visualization. This code plots on a map all of the GPS locations that an end node sent to its respective channel on the current day. The code also plots polygons on the map that represent different fields and it counts the number of end node GPS coordinates that are located in each polygon. Originally, this code was going to serve as the tool that agricultural managers could use to view end node locations over time, but do to random display issues with the MATLAB Visualizations, the non-interactive nature of the map, and the small scale of the output, this was abandoned. However, this code can still serve to teach how to create MATLAB Visualizations in ThingSpeak if future teams wish to implement them. The display that results from this piece of code can be seen below. 

<p align="center">
	
</p>

### Unrealized Boundary Status

An aspect of our project that was not fully realized was the “Out of Bounds” flag in ThingSpeak and in the GUI. How this operation works is there is code for every device’s ThingSpeak channel, in ThingSpeak_Plotting, that checks if the number of GPS locations recorded by an end node on the current day is within a preconfigured polygon that represents the perimeter of the site. If an end node’s GPS location is outside of this polygon, field 6 of that corresponding device’s channel is set to 1, which subsequently triggers a ThingSpeak React that sends an email notification. The Python GUI was also configured to display this Out of Bounds flag and indicate the location of the out of bounds device. 

<p align="center">
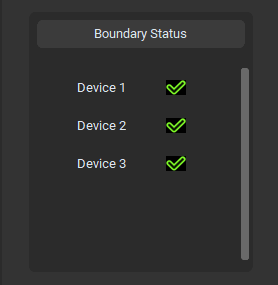
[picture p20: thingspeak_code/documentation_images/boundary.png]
	
</p>

This out of bounds check was done in ThingSpeak for the purpose of utilizing a React that could send notifications, however, because there are a limited number of ThingSpeak writes that can be performed in a short period of time, our implementation was ultimately unsuccessful. This ThingSpeak limitation, among the other limitations of ThingSpeak’s processing capabilities, could be circumvented by having the out of bounds check be performed in the Python GUI code. To configure a React for this out of bounds flag, exploration is needed in sending data from Python back to a specified ThingSpeak channel field by using the ThingSpeak API. 

The code that alters the boundary status flag was designed to be integrated with the ThingSpeak_Plotting code that was previously described. The boundary check is still completed within the code, but any "thingSpeakWrite" functions that alter field 6 of a channel have been commented out to avoid the MATLAB errors that result from too many writes occurring within an allotted time window. This "thingSpeakWrite" limitation may be circumvented by upgrading to another ThingSpeak license, but I do not think that thingSpeakWrite functionality is important enough to warrant the extra cost.

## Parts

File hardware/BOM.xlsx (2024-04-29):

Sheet: Sheet1
Item | Quantity | Designator | Description | Value | Manufacturer or Retailer | Link | Manufacturer Part Number | Cost
1 | 1 | U1 | CubeCell GPS-6502 | 902-928 MHz | Heltec Automation | https://heltec.org/project/htcc-ab02s/ | HTCC-AB02S | $25.90
2 | 1 | U3 | Bluefruit LE UART Friend | - | Adafruit | https://www.adafruit.com/product/2479 | 2479 | $17.50
3 | 1 | D1 | Green LED | - | Generic | - | - | $0.29
4 | 1 | D2 | Schottky Power Diode | - | STMicroelectronics | https://www.digikey.com/en/products/detail/stmicroelectronics/1N5819/1037326 | 1N5819 | $0.38
5 | 2 | C1, C3 | Ceramic Through-Hole Capacitor | 100 nF | Generic | - | - | $0.44
6 | 1 | C2 | Electrolytic Through-Hole Capacitor | 100 uF | Generic | - | - | $0.24
7 | 4 | R1, R2, R3, R4 | Axial Through-Hole Resistor | 1 kΩ | Generic | - | - | $0.40
8 | 1 | R5 | Axial Through-Hole Resistor | 10 kΩ | Generic | - | - | $0.10
9 | 1 | R6 | Axial Through-Hole Resistor | 4.7 kΩ | Generic | - | - | $0.10
10 | 1 | R7 | Axial Through-Hole Resistor | 3 kΩ | Generic | - | - | $0.10
11 | 1 | P1, P2 | Male Pin Header | - | Generic | - | - | $0.80
12 | 6 | - | Screw Terminals | - | Pololu Electronics | https://www.pololu.com/product/2440 | - | $3.00
13 | 3 | - | Waterproof Momentary Push Button Switch | - | Apiele | https://www.amazon.com/APIELE-Momentary-Waterproof-PBS-33B-Pre-soldered/dp/B09V2KZZ8W | - | $4.25
14 | 1 | - | Waterproof Round Rocker Switch | - | Tesorrio | https://www.amazon.com/Terminal-Rocker-Switch-Swithcher-Button/dp/B07VLMDCWG?s=industrial | - | $3.40
15 | 1 | - | Rechargeable Power Bank | 5000mAh/5V/2.4A | Miady | https://www.amazon.com/Miady-Portable-Charger-5000mAh-Lightweight/dp/B083VRD7CX?th=1 | - | $17.99
16 | 1 | - | IP68 NEMA 6P Box with Clear Cover | - | Bud Industries, Inc. | https://www.budind.com/product/nema-ip-rated-boxes/pn-a-series-nema-6p-box/ip68-nema-6p-box-with-clear-cover-pn-1332-ac/ | PN-1332-AC | $11.65
17 | 1 | - | Printed Circuit Board | - | JLCPCB | - | - | $1.66
 |  |  |  |  |  |  | Total Cost | $88.20

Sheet: Sheet2
Item | Quantity | Value | Designator | Description | Manufacturer | Manufacturer Part Number | Cost
1 | 5 | N/A | N/A | Printed Circuit Boards | PCBWay | W626245AS1F1 | $54.38
2 | 1 | N/A | U4 | Linear Voltage Regulator IC | Texas Instruments | LM2940CT-5.0 | $1.87
3 | 1 | N/A | U1 | Microcontroller Board | Raspberry Pi | Raspberry Pi Pico | $4.00
4 | 1 | N/A | DS1 | LCD Screen | Crystalfontz | CFAH1602Z-YYH-ET | $15.10
5 | 1 | N/A | J1 | 8 Ohm Speaker | PUI Audio, Inc. | AS02008MR-5-R | $2.63
6 | 1 | N/A | U3 | Audio Amplifier IC | Texas Instruments | LM386N-1 | $1.28
7 | 1 | N/A | U2 | DAC IC | Analog Devices | LT1661 | $5.43
8 | 1 | N/A | P1 | 2 Pin Female Header | Sullins Connector Solutions | PPTC021LFBN-RC | $0.33
9 | 1 | N/A | S3 | SPDT Toggle Switch | E-Switch | 100SP1T1B1M1QEH | $1.68
10 | 2 | N/A | S1, S2 | Tactile Switch | TE Connectivity ALCOSWITCH Switches | 1825910-6 | $0.13
11 | 2 | 10k ohm | R1, R2 | 10K NTC Thermistor | Murata Electronics | NXRT15XH103FA1B030 | $0.43
12 | 1 | 10k ohm | R8 | 10k Trimmer Potentiometer | SparkFun Electronics | COM-09806 | $1.05
13 | 1 | N/A | D3 | Schottky Diode | Taiwan Semiconductor Corporation | 1N5819 | $0.39
14 | 2 | N/A | D1, D2 | Red LED | SunLED | XLUR12D | $0.28
15 | 6 | 100 nF | C2, C7, C9, C11, C5, C10 | Ceramic Capacitor | KEMET | C322C104K5R5TA7301 | $0.29
16 | 1 | 10 uF | C4 | Electrolytic Capacitor | Nichicon | UCS2G100MPD1TD | $1.07
17 | 4 | 100 uF | C8, C1, C3, C6 | Electrolytic Capacitor | Rubycon | 100ZLH100MEFC10X20 | $0.79
18 | 4 | 10k ohms | R3, R4, R14, R10 | Resistor | Stackpole Electronics Inc | CF14JT10K0 | $0.10
19 | 3 | 1k ohms | R6, R7, R15 | Resistor | Stackpole Electronics Inc | CF14JT1K00 | $0.10
20 | 4 | 330 ohms | R5, R9, R12, R16 | Resistor | Stackpole Electronics Inc | CF14JT330R | $0.10
21 | 1 | 220 ohms | R17 | Resistor | Stackpole Electronics Inc | CF18JT220R | $0.10
22 | 1 | 10 ohms | R13 | Resistor | Bourns Inc. | FW20A10R0JA | $0.65
23 | 1 | 1.5 ohms | R11 | Resistor | YAGEO | FMP200JR-52-1R5 | $0.37
 |  |  |  |  |  | Total Cost | $92.55

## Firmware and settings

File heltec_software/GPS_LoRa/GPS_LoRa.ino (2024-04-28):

#include <Wire.h>
#include <Arduino.h>
#include <SPI.h>
#include "Adafruit_BLE.h"
#include "Adafruit_BluefruitLE_UART.h"

#include "BluefruitConfig.h"

#include "GPS_Air530.h"
#include "GPS_Air530Z.h"  
#include "HT_SSD1306Wire.h"
#include "LoRaWan_APP.h"

// note that the select button is being used to turn on/off BLE communication
// note that the toggle button is being used to toggle the display

//************************************************************************* Variables and Defines ************************************************************************************

#define BUTTON_POWER GPIO7
#define EMERGENCY_BUTTON GPIO6
#define SELECT_BUTTON GPIO5
#define TOGGLE_BUTTON USER_KEY
#define LED GPIO9

// defines for the BLE module
#define FACTORYRESET_ENABLE         0
#define NEW_BLE_NAME               "LIAM DEVICE" // change this to whatever you want the name of the BLE module to beacon as
#define MINIMUM_FIRMWARE_VERSION    "0.6.6"
#define MODE_LED_BEHAVIOUR          "DISABLE"

// initializes BLE module
Adafruit_BluefruitLE_UART ble(Serial1, BLUEFRUIT_UART_MODE_PIN); //serial1 for tx2 and rx2

// initializes the OLED display
SSD1306Wire  display(0x3c, 500000, SDA, SCL, GEOMETRY_128_64, GPIO10); // addr , freq , SDA, SCL, resolution , rst

// initializes GPS
Air530ZClass GPS;

// array of strings containing the messages to be displayed on the OLED upon a particular downlink message being received from TTN server
static const char* downlink_mess[] = {
  "",
  "Return within Bounds",
  "Return to Base",  
  "Move to Field A", 
  "Move to Field B",
  "Rain Expected",
  "High Heat Alert",
  "Return Device to Base"
};

// array of strings containing the messages to be displayed on the OLED upon a particular string being received on the BLE module
// these strings correspond to the message code that will be sent to the server in an uplink
static const char* uplink_mess[] = {
  "",
  "Task complete", //complete
  "Starting Task", //start
  "Need a hand", //hand
  "Repair Needed", //repair
  "Pest Sighting", //pest
  "Equipment Malfunction", //malf
  "Deliveries Arrived" //deliv
};

//================================================= Arrays used to send fake GPS data to server for testing and demonstration purposes ==================================================================
// this mock GPS data will only be sent to server if "debug = 1"

//Device 1
/*
int lat_debug_iterable[] = {542124, 542105, 542577, 543149, 543639, 543873, 544345, 545019, 545861, 545805, 545777, 545750, 546249, 547163, 547801, 548291};
int long_debug_iterable[] = {586105, 587607, 588347, 588004, 586373, 587232, 588237, 586316, 586424, 587561, 588752, 590780, 591810, 590704, 588548, 586391};
int debug_array_size = 16;
*/

//Device 2
/*
int lat_debug_iterable[] = {542109, 542257, 542377, 543061, 543440, 543597, 543699, 544050, 544909, 545574, 545787, 545796, 545556, 545353, 545020, 544576};
int long_debug_iterable[] = {594707, 595565, 596671, 597250, 597647, 598612, 599900, 600715, 600715, 600093, 599256, 598387, 597293, 596456, 595887, 595308};
int debug_array_size = 16;
*/

//Device 3
///*
int lat_debug_iterable[] = {549455, 549973, 550675, 551312, 551765, 551894, 551950, 551922, 551913, 551922, 551996, 552033, 551663, 551294, 551118, 550776, 550481, 550585, 550356, 550088, 550015};
int long_debug_iterable[] = {600577, 600609, 600469, 600287, 600062, 599364, 598603, 597723, 597133, 596467, 595824, 595201, 595159, 595094, 595094, 595094, 595631, 596278, 596913, 597782, 598447};
int debug_array_size = 21;
//*/

//========================================================================================================================================================================================================

int debug = 0; // controls whether real GPS data is sent to server, or mock data (0 for real, 1 for mock)
int debug_iterator = 0;

uint32_t downlink_data = 0;

uint8_t switch_flag = 0;
uint8_t emergency_flag = 0;
uint8_t emergency_button_counter = 0;
bool emergency_button_ready = false;
uint16_t select_flag = 0;
uint8_t toggle_flag = 0;
uint8_t up_message_flag = 0;
uint8_t down_message_flag = 0;

uint32_t starting;
uint8_t run_once = 0;
uint8_t ble_run_once = 0;
uint8_t ble_disp_run_once = 0;

uint32_t emergency_timer;
uint32_t timer2;

int batteryVoltage = 0;
uint16_t battery_Voltage = 0;

int32_t lng_int_part = 0;
int32_t lng_tmp;
uint32_t lng_frac_part = 0;

int32_t lat_int_part = 0;
int32_t lat_tmp;
uint32_t lat_frac_part = 0;

extern TimerEvent_t TxNextPacketTimer; // had to add this so that the timer that controls LoRaWAN wake up from low power mode can be turned off when the program enters the DEVICE_STATE_IDLE switch case
// turning off this timer ensures that the program will stay in DEVICE_STATE_IDLE until the toggle button is pressed (rather than exiting this switch case upon the timer overflowing)

//======================================= The OTAA parameters that have been specified for each of the three devices in TheThingsNetwork ===============================================================
// swapping OTAA parameters makes TTN think that data is being sent from a different device

/* OTAA para for Liam*/
///*
uint8_t devEui[] = { 0x70, 0xb3, 0xd5, 0x7e, 0xd0, 0x06, 0x53, 0x89 };
uint8_t appEui[] = { 0x00, 0x00, 0x00, 0x00, 0x00, 0x00, 0x00, 0x00 };
uint8_t appKey[] = { 0xcc, 0xb4, 0x5e, 0xba, 0xfb, 0xd7, 0x60, 0x07, 0x9c, 0x0d, 0xf0, 0x51, 0x17, 0x30, 0x29, 0x4e };
//*/

/* OTAA para for Justin*/
/*
uint8_t devEui[] = { 0x70, 0xb3, 0xd5, 0x7e, 0xd0, 0x06, 0x55, 0xE1 };
uint8_t appEui[] = { 0x00, 0x00, 0x00, 0x00, 0x00, 0x00, 0x00, 0x00 };
uint8_t appKey[] = { 0x3f, 0xc8, 0x0d, 0x40, 0x41, 0xdb, 0xe9, 0xb2, 0x5b, 0x9c, 0xc7, 0xaf, 0xd1, 0xd4, 0x66, 0xd6 };
*/

/* OTAA para for Maria*/
/*
uint8_t devEui[] = { 0x70, 0xb3, 0xd5, 0x7e, 0xd0, 0x06, 0x54, 0xCB };
uint8_t appEui[] = { 0x00, 0x00, 0x00, 0x00, 0x00, 0x00, 0x00, 0x00 };
uint8_t appKey[] = { 0xF5, 0x56, 0x03, 0xED, 0x90, 0x74, 0x5A, 0x3C, 0xB2, 0xFA, 0xA4, 0x36, 0x1B, 0x5F, 0xFA, 0x4C };
*/

//========================================================================================================================================================================================================

// ABP para -> these are irrelevant because we use OTAA as it is more secure
uint8_t nwkSKey[] = { 0x6E, 0xD6, 0xC2, 0xBC, 0x0B, 0xAE, 0x0B, 0x03, 0x0C, 0x9B, 0x19, 0xBC, 0xF5, 0x96, 0xD3,0x24 };
uint8_t appSKey[] = { 0x5E, 0x3B, 0x4F, 0xB3, 0x33, 0xB7, 0x6F, 0xF3, 0x57, 0x11, 0x0D, 0x6C, 0x3F, 0x9A, 0x0F,0x93 };
uint32_t devAddr =  ( uint32_t )0x260c83F6;

/*LoraWan channelsmask, default channels 0-7*/ 
uint16_t userChannelsMask[6]={ 0xFF00,0x0000,0x0000,0x0000,0x0000,0x0000 };

/*LoraWan region, select in arduino IDE tools*/
LoRaMacRegion_t loraWanRegion = ACTIVE_REGION;

/*LoraWan Class, Class A and Class C are supported*/
DeviceClass_t  loraWanClass = LORAWAN_CLASS;

/*the application data transmission duty cycle.  value in [ms].*/
uint32_t appTxDutyCycle = 15000; // right now it is set to 15s, meaning that every ~15s, an uplink message will be sent to the server

/*OTAA or ABP*/
bool overTheAirActivation = LORAWAN_NETMODE;

/*ADR enable*/
bool loraWanAdr = LORAWAN_ADR;

/* set LORAWAN_Net_Reserve ON, the node could save the network info to flash, when node reset not need to join again */
bool keepNet = LORAWAN_NET_RESERVE;

/* Indicates if the node is sending confirmed or unconfirmed messages */
bool isTxConfirmed = LORAWAN_UPLINKMODE;

/* Application port */
uint8_t appPort = 2;
/*!
* Note, that if NbTrials is set to 1 or 2, the MAC will not decrease
* the datarate, in case the LoRaMAC layer did not receive an acknowledgment
*/
uint8_t confirmedNbTrials = 4;

//**************************************************************************************************************************************************************************************************

//*********************************************************************************** Functions *************************************************************************************************

// A small helper for BLE code
void error(const __FlashStringHelper*err) {
  Serial.println(err);
  while (1);
}

// function used for converting GPS data
int32_t fracPart(double val, int n) 
{
  return (uint32_t)abs((val - (int32_t)(val))*pow(10,n));
}

// turns OLED display ON
void VextON(void)
{
  pinMode(Vext,OUTPUT);
  digitalWrite(Vext, LOW);
}

// turns OLED display off
void VextOFF(void)
{
  pinMode(Vext,OUTPUT);
  digitalWrite(Vext, HIGH);
}

// interrupt service routine for when emergency button (red button) is held down
void EMERGENCYButtonPress(void) {
  // had to turn off interrupts and make a large debouncing delay on this button's ISR because for some reason this GPIO reads a falling edge whenever the board is booting up
  // which incorrectly triggers the ISR --> this makes it so that the Emergency button has to be held down to activate the ISR, which protects against an emergency signal accidentally being sent
  noInterrupts();
  delay(800);
  if (emergency_button_ready == true) {

      // if button has been held down once, displays "Emergency Signal Sent" on OLED and the emergency flag is changed, which will then be sent in the next uplink message
      if (emergency_button_counter == 1 && digitalRead(EMERGENCY_BUTTON) == 0) {
          Serial.print("Emergency button has been pressed twice");
          Serial.println();
          emergency_button_counter = 2;
          emergency_flag = 0xFF;
          Display_Emergency_Press(emergency_button_counter);
      }
      // if button has been held down once, displays "Send Emergency Signal" on OLED
      if (digitalRead(EMERGENCY_BUTTON) == 0 && emergency_button_counter == 0) {
        Serial.print("Emergency button has been pressed once");
        Serial.println();
        emergency_button_counter = 1;
        Display_Emergency_Press(emergency_button_counter);
        }

        // variable initialized with current time, which is used to determine how much time has elapsed since the the emergency button has been pressed
        emergency_timer = millis();
  }

    delay(1000);
    interrupts();
}

// interrupt service routine for when select button (blue button) is pressed
void SELECTButtonPress(void) {
  delay(20);
  // if select button is pressed, the BLE is turned on/off and corresponding message on OLED is displayed
  if (digitalRead(SELECT_BUTTON) == 0) {
    Serial.print("Select button has been pressed");
    Serial.println();
    select_flag = select_flag + 1;
    if (select_flag%2 == 1) {
      Serial.print("Turning on BLE");
      Serial.println();
      Display_BLE_Status(select_flag);
      deviceState = DEVICE_STATE_IDLE;
    }
    else {
      Serial.print("Turning off BLE");
      Serial.println();
      Display_BLE_Status(select_flag);
      delay(1000);
      GPS.begin(9600); // GPS is turned on after BLE communication is stopped because the GPS has to be turned off when
      // BLE communication starts, as the BLE and GPS share Serial1 (RX2 and TX2) on the Heltec
      ble_run_once = 0;
      deviceState = DEVICE_STATE_INIT;
    }
}

}

// interrupt service routine for when toggle button (green button) is pressed
void TOGGLEButtonPress(void) {
  delay(20);
  // if toggle button is pressed, the OLED is turned on/off
  // when OLED is turned on, the current longitude, latitude, and battery voltage (mV) of the end node are displayed
  if (digitalRead(TOGGLE_BUTTON) == 0) {
    Serial.print("Toggle button has been pressed");
    Serial.println();
    toggle_flag = toggle_flag + 1;
    if (toggle_flag%2 == 1) {
      Serial.print("Turning on display");
      Serial.println();
      Display_Crit_Info();
    }
    else {
      Serial.print("Turning off display");
      Serial.println();
      display.clear();
      display.display();

      VextOFF();
    }
}
}

// displays on OLED whether the BLE is being turned on or off based on the value of input argument
void Display_BLE_Status(uint16_t select_flag) {

  VextON(); // turns on OLED 
  delay(100);

  display.clear(); // clears OLED display
  display.display(); // makes the OLED screen empty

  // formatting on OLED
  display.setTextAlignment(TEXT_ALIGN_CENTER); 
  display.setFont(ArialMT_Plain_10);

  if (select_flag%2 == 1) {
      char str[30];
      sprintf(str,"Turning");
      display.drawString(64, 14, str);
      sprintf(str,"ON");
      display.drawString(64, 28, str);
      sprintf(str,"BluetoothLE");
      display.drawString(64, 42, str);
  }

  if (select_flag%2 == 0) {
      char str[30];
      sprintf(str,"Turning");
      display.drawString(64, 14, str);
      sprintf(str,"OFF");
      display.drawString(64, 28, str);
      sprintf(str,"BluetoothLE");
      display.drawString(64, 42, str);
  }
   display.display(); // displays on OLED what was input to .drawString()

   delay(2000);

   display.clear();
   display.display();

   VextOFF();
}

// displays on OLED information about emergency message based on the value of input argument
void Display_Emergency_Press(uint8_t emergency_button_counter) {

  VextON();
  delay(100);

  display.clear();
  display.display();

  display.setTextAlignment(TEXT_ALIGN_CENTER);
  display.setFont(ArialMT_Plain_10);

  if (emergency_button_counter == 1) {
      char str[30];
      sprintf(str,"Send");
      display.drawString(64, 14, str);
      sprintf(str,"Emergency");
      display.drawString(64, 28, str);
      sprintf(str,"Signal?");
      display.drawString(64, 42, str);
  }

  if (emergency_button_counter == 2) {
      char str[30];
      sprintf(str,"Emergency");
      display.drawString(64, 14, str);
      sprintf(str,"Signal");
      display.drawString(64, 28, str);
      sprintf(str,"Sent");
      display.drawString(64, 42, str);
  }
  
  display.display();
}
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
void loop()
{
  
  if (emergency_button_counter != 0) {
    if ((uint32_t)round((millis()-emergency_timer)/1000) > 10) { // if more than 10 seconds has elapsed since the Emegency button has been held down
    // then the OLED display is cleared so that the emergency status messages disappear; emergency_button_counter is set to 0 after 10 seconds as well
    // meaning that if the emergency button was held down once and not held down again within the 10 second window, then the emergency button will
    // once again have to be held down twice in order to send an emergency signal
      Serial.print("Emergency timed out, loser");
      Serial.println();
      emergency_button_counter = 0;
      display.clear();
      display.display();

      VextOFF();
    }
  }

	switch( deviceState )
	{
      case DEVICE_STATE_IDLE:  // switch block for BLE communication only
      {

        if (ble_run_once == 0) {
          TimerStop( &TxNextPacketTimer ); // stop the LoRaWAN timer so that this switch block is not exited prematurely

          VextON();
          delay(100);

          GPS.end(); // turning off GPS because the BLE and GPS share Serial1 
          delay(1000);

          InitializeBLE(); // initializing BLE once again
          ble_run_once = 1;
        }
        // Check for incoming characters from Bluefruit
          ble.println("AT+BLEUARTRX");
          ble.readline();

          if (ble.buffer[0]=='c' && ble.buffer[1]=='o' && ble.buffer[2]=='m' && ble.buffer[3]=='p' && ble.buffer[4]=='l' && ble.buffer[5]=='e' && ble.buffer[6]=='t' && ble.buffer[7]=='e') {
            Serial.print("Task complete"); // if "complete" is received by BLE, uplink message flag is sent to 1, corresponding to the message "Task complete"
            Serial.println();
            ble_disp_run_once = 0;
            up_message_flag = 1;
          }
          if (ble.buffer[0]=='s' && ble.buffer[1]=='t' && ble.buffer[2]=='a' && ble.buffer[3]=='r' && ble.buffer[4]=='t') {
            Serial.print("Starting Task"); // if "start" is received by BLE, uplink message flag is sent to 2, corresponding to the message "Starting Task"
            Serial.println();
            ble_disp_run_once = 0;
            up_message_flag = 2;
          }
          if (ble.buffer[0]=='h' && ble.buffer[1]=='a' && ble.buffer[2]=='n' && ble.buffer[3]=='d') {
            Serial.print("Need a hand"); // if "hand" is received by BLE, uplink message flag is sent to 3, corresponding to the message "Need a hand"
            Serial.println();
            ble_disp_run_once = 0;
            up_message_flag = 3;
          }
          if (ble.buffer[0]=='r' && ble.buffer[1]=='e' && ble.buffer[2]=='p' && ble.buffer[3]=='a' && ble.buffer[4]=='i' && ble.buffer[5]=='r') {
            Serial.print("Repair Needed"); // if "repair" is received by BLE, uplink message flag is sent to 4, corresponding to the message "Repair Needed"
            Serial.println();
            ble_disp_run_once = 0;
            up_message_flag = 4;
          }
          if (ble.buffer[0]=='p' && ble.buffer[1]=='e' && ble.buffer[2]=='s' && ble.buffer[3]=='t') {
            Serial.print("Pest Sighting"); // if "pest" is received by BLE, uplink message flag is sent to 5, corresponding to the message "Pest Sighting"
            Serial.println();
            ble_disp_run_once = 0;
            up_message_flag = 5;
          }
          if (ble.buffer[0]=='m' && ble.buffer[1]=='a' && ble.buffer[2]=='l' && ble.buffer[3]=='f') {
            Serial.print("Equipment Malfunction"); // if "malf" is received by BLE, uplink message flag is sent to 6, corresponding to the message "Equipment Malfunction"
            Serial.println();
            ble_disp_run_once = 0;
            up_message_flag = 6;
          }
          if (ble.buffer[0]=='d' && ble.buffer[1]=='e' && ble.buffer[2]=='l' && ble.buffer[3]=='i' && ble.buffer[4]=='v') {
            Serial.print("Deliveries Arrived"); // if "deliv" is received by BLE, uplink message flag is sent to 7, corresponding to the message "Deliveries Arrived"
            Serial.println();
            ble_disp_run_once = 0;
            up_message_flag = 7;
          }

          if (ble_disp_run_once == 0) {
            Display_Uplink_Message(up_message_flag); // displays message corresponding to uplink message flag on the OLED
          }

          if (ble.buffer[0]=='s' && ble.buffer[1]=='e' && ble.buffer[2]=='n' && ble.buffer[3]=='d') { // if "send" is received by BLE, the OLED display is turned off, the GPS is turned 
          // on and reinitialized, and this BLE switch block is exited so that LoRaWAN communication can once again be established
            select_flag = select_flag + 1; 
            Serial.print("Turning off BLE");
            Serial.println();

            display.clear();
            display.display();

            VextOFF();

            delay(1000);
            GPS.begin(9600);
            ble_run_once = 0;

            deviceState = DEVICE_STATE_INIT;
          }
            break;

    }
		case DEVICE_STATE_INIT: // initializes the LoRaWAN module using init(), which sets LoRaWAN parameters, region, abd the LoRaWAN timer ISR
		{
#if(LORAWAN_DEVEUI_AUTO)
			LoRaWAN.generateDeveuiByChipID();
#endif
#if(AT_SUPPORT)
			getDevParam();
#endif
			printDevParam();
			LoRaWAN.init(loraWanClass,loraWanRegion);
			deviceState = DEVICE_STATE_JOIN;
			break;
		}
		case DEVICE_STATE_JOIN: // joins the server and chooses appropriate next switch block based on parameters
		{
			LoRaWAN.join();
			break;
		}
		case DEVICE_STATE_SEND: // performs intermediate processing, prepares payload of frame, and sends uplink message to server
		{
      // reads data from GPS and decodes it
      starting = millis();
      while( (millis()-starting) < 1000 ) {
         while (GPS.available() > 0) {
          GPS.encode(GPS.read());
          }
          }

      if(( (lng_frac_part != 0) && run_once == 0)){ // when the GPS sets, the time that it took for the GPS to set is displayed on the OLED

        uint32_t time_elapsed = (uint32_t)round((millis()-timer2)/1000);

        Display_GPS_Set(time_elapsed, 10000); 

        run_once = 1;
      }

      if(down_message_flag != 0){ // if a downlink message has been received from TTN and it matches one of the preconfigured downlink codes, the message corresponding
      // to that downlink code is displayed on the OLED for 10 seconds
        Display_Downlink_Message(down_message_flag, 10000);
        down_message_flag = 0;
      }

			prepareTxFrame( appPort ); // prepares frame to be transmitted in uplink message
			LoRaWAN.send(); // sends the frame to the server
			deviceState = DEVICE_STATE_CYCLE; // moves to switch block that schedules next packet transmission
			break;
		}
		case DEVICE_STATE_CYCLE: // sets the value for the LoRaWAN timer and starts the timer, which will ensure that the Heltec exits low power mode to send another uplink message
    // after "appTxDutyCycle" seconds
		{
			// Schedule next packet transmission
			txDutyCycleTime = appTxDutyCycle + randr( 0, APP_TX_DUTYCYCLE_RND ); // timer set to overflow after "appTxDutyCycle + small random delay" seconds 
			LoRaWAN.cycle(txDutyCycleTime);
			deviceState = DEVICE_STATE_SLEEP; // movs to switch block that places Heltec in low power mode
			break;
		}
		case DEVICE_STATE_SLEEP:
		{
			LoRaWAN.sleep(); // places Heltec in low power mode
			break;
		}
		default:
		{
			deviceState = DEVICE_STATE_INIT;
			break;
		}
	}
}

//****************************************************************************************************************************************************************************************

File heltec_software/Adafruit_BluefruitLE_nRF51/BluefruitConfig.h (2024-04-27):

// COMMON SETTINGS
// ----------------------------------------------------------------------------------------------
// These settings are used in both SW UART, HW UART and SPI mode
// ----------------------------------------------------------------------------------------------
#define BUFSIZE                        128   // Size of the read buffer for incoming data
#define VERBOSE_MODE                   true  // If set to 'true' enables debug output


// SOFTWARE UART SETTINGS
// ----------------------------------------------------------------------------------------------
// The following macros declare the pins that will be used for 'SW' serial.
// You should use this option if you are connecting the UART Friend to an UNO
// ----------------------------------------------------------------------------------------------
#define BLUEFRUIT_SWUART_RXD_PIN       9    // Required for software serial!
#define BLUEFRUIT_SWUART_TXD_PIN       10   // Required for software serial!
#define BLUEFRUIT_UART_CTS_PIN         11   // Required for software serial!
#define BLUEFRUIT_UART_RTS_PIN         -1   // Optional, set to -1 if unused


// HARDWARE UART SETTINGS
// ----------------------------------------------------------------------------------------------
// The following macros declare the HW serial port you are using. Uncomment
// this line if you are connecting the BLE to Leonardo/Micro or Flora
// ----------------------------------------------------------------------------------------------
#ifdef Serial1    // this makes it not complain on compilation if there's no Serial1
  #define BLUEFRUIT_HWSERIAL_NAME      Serial1
#endif


// SHARED UART SETTINGS
// ----------------------------------------------------------------------------------------------
// The following sets the optional Mode pin, its recommended but not required
// ----------------------------------------------------------------------------------------------
#define BLUEFRUIT_UART_MODE_PIN        -1    // Set to -1 if unused--> we will not be using the mode pins


// SHARED SPI SETTINGS
// ----------------------------------------------------------------------------------------------
// The following macros declare the pins to use for HW and SW SPI communication.
// SCK, MISO and MOSI should be connected to the HW SPI pins on the Uno when
// using HW SPI.  This should be used with nRF51822 based Bluefruit LE modules
// that use SPI (Bluefruit LE SPI Friend).
// ----------------------------------------------------------------------------------------------
#define BLUEFRUIT_SPI_CS               8
#define BLUEFRUIT_SPI_IRQ              7
#define BLUEFRUIT_SPI_RST              4    // Optional but recommended, set to -1 if unused

// SOFTWARE SPI SETTINGS
// ----------------------------------------------------------------------------------------------
// The following macros declare the pins to use for SW SPI communication.
// This should be used with nRF51822 based Bluefruit LE modules that use SPI
// (Bluefruit LE SPI Friend).
// ----------------------------------------------------------------------------------------------
#define BLUEFRUIT_SPI_SCK              13
#define BLUEFRUIT_SPI_MISO             12
#define BLUEFRUIT_SPI_MOSI             11
